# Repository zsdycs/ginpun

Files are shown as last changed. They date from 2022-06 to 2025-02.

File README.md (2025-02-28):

## GinPun

> 即：键盘（粤语）

偶然看到开源键盘库 [system76/launch](https://github.com/system76/launch) ，受其启发，故折腾起键盘。

目前有三款（[KB84](kb84/)、[SG_V1](sg_v1/)、[SG_V2](sg_v2/)）键盘，都是基于 ATmega 32U4 的。

更便宜一些的 ATmega 32A 的引导程序和最小系统也有提供，但是经过开发板打样测试，32A 的性能对于运行 QMK 来说还是捉襟见肘的，可玩性稍低一些。

例如：

- 在显示“从右向左”的五彩灯效时，会有停顿。
- 由于不支持 USB，通过 V-USB 实现的 USB，也不可以实现全键无冲。

## 指南💡

请移步阅读博客 [【一起做个机械键盘吧⌨️】](https://lipk.org/blog/2023-02-10-Let-s-make-a-keyboard)

## KB84

[KB84 于立创开源社区的链接](https://oshwhub.com/lipk/keyboard_1)

按键布局基于 system76 的 [launch](https://system76.com/accessories/launch) 键盘。由于特殊设计的按键配列，键帽非常难买到，键帽高度只能买到 XDA 的，可玩性不高。

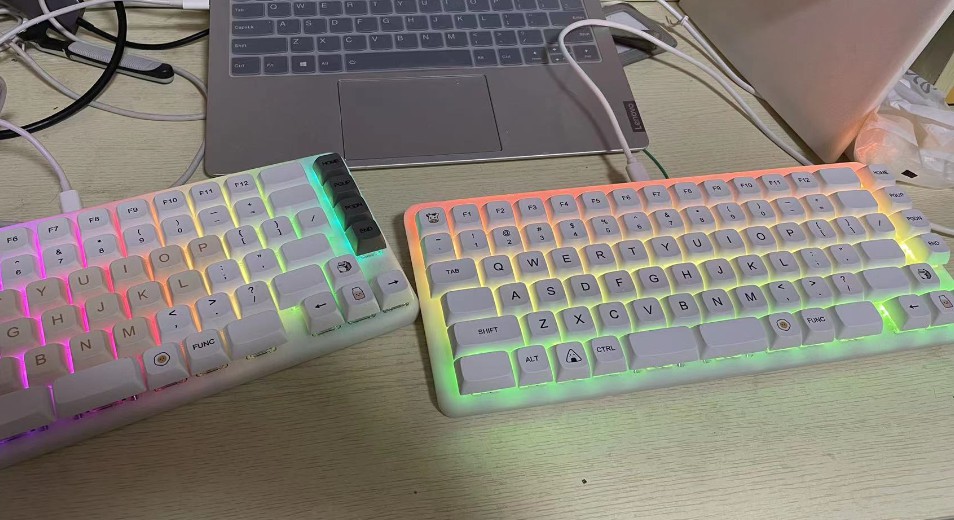
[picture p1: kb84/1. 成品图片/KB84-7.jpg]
KB84 成品图片1


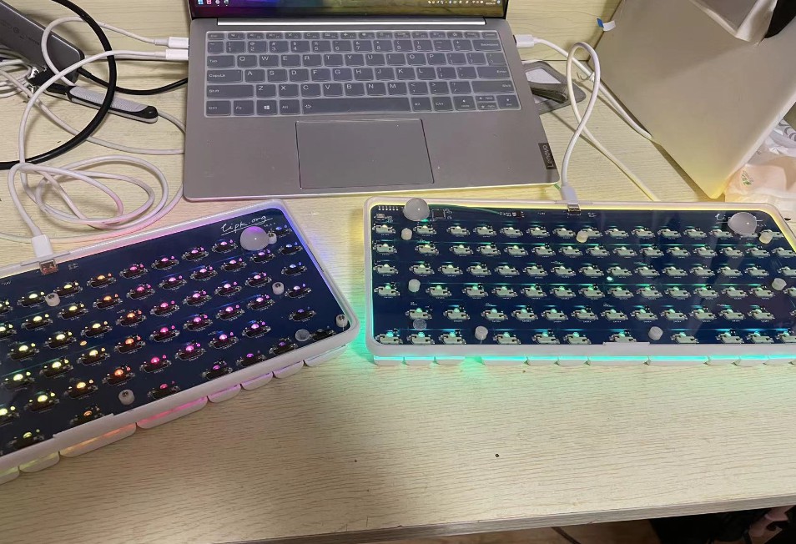
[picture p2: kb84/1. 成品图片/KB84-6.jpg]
KB84 成品图片2


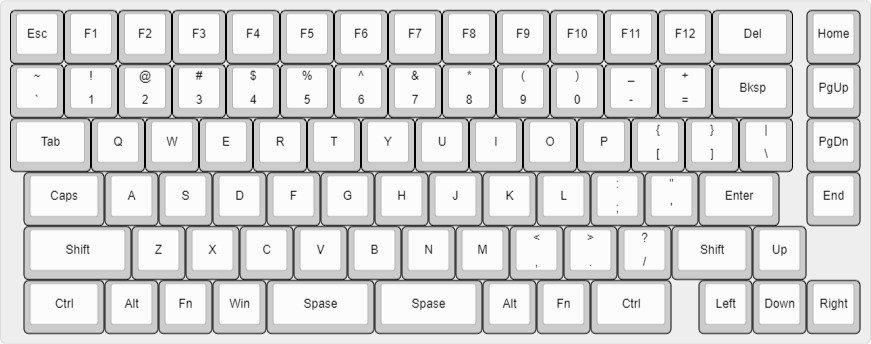
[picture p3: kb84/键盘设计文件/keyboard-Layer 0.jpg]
KB84 配列展示


### SG_V1

类标准 84 配列。

主要特点是第 6 行，“空格”键居中，有一个 1.5U 的 “CTRL” 靠近 “Z”、“X”、“C”、“V”，方便使用快捷键，所以键帽购买时也是稍微需要注意的。

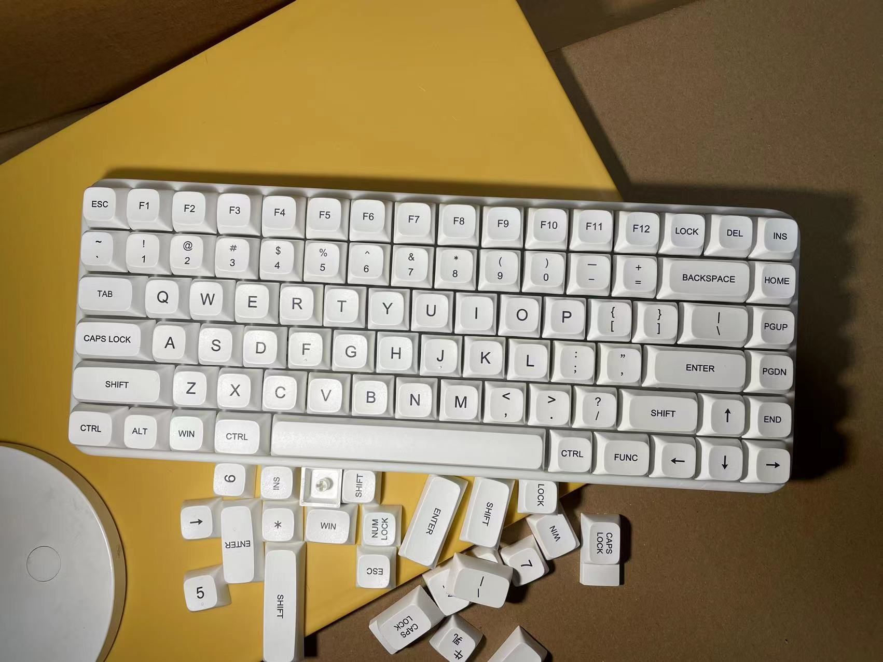
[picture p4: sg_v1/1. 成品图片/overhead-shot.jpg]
SG_V1 成品图片1


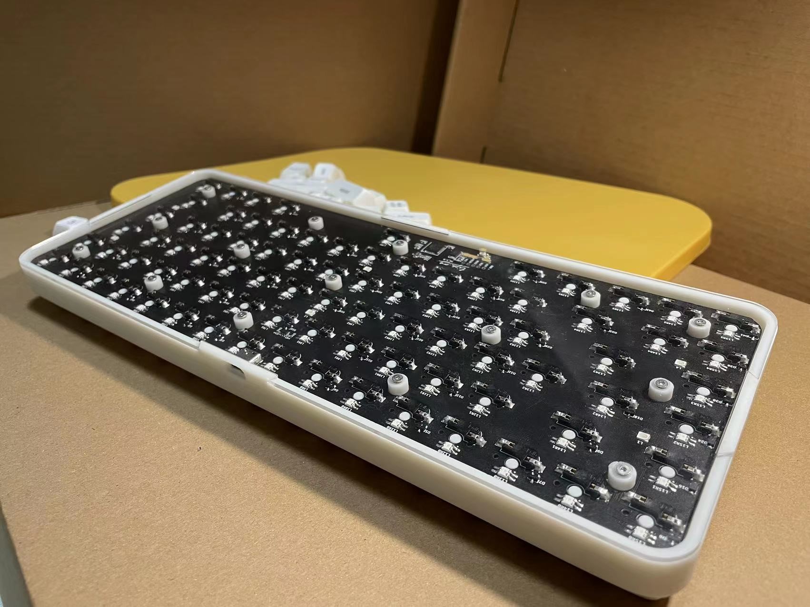
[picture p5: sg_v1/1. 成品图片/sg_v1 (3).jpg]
SG_V1 成品图片2


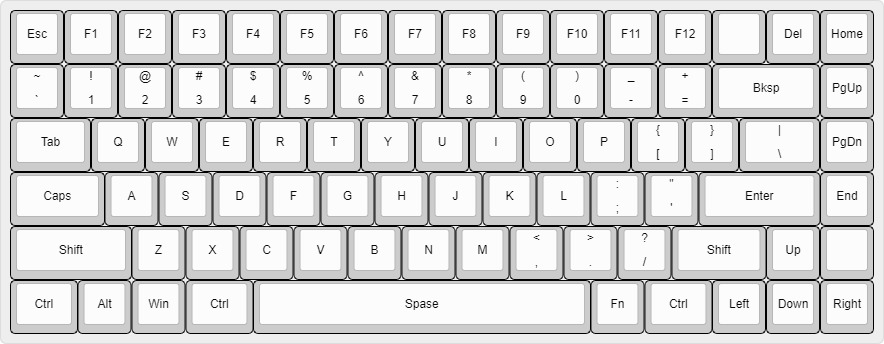
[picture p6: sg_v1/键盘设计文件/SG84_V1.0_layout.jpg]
SG_V1 配列展示


### SG_V2

[SG_V2 于立创开源硬件平台的链接](https://oshwhub.com/lipk/SG-61)

标准 87 配列，去掉右侧方向键和功能键，再去掉 F 区就是 SG_V2 的配列了。

由于是在“标准 87 配列”的基础上做删减，所以直接买 87 配列的键帽就好了，可玩性很高。

另外，此键盘使用 gasket 结构设计，而且使用磁吸安装，不需要一颗螺丝。

注：F 区，和方向键、功能键都在第 2 层，只要按一下功能键就可以切换到第 2 层了，不会有按键不够用的苦恼。

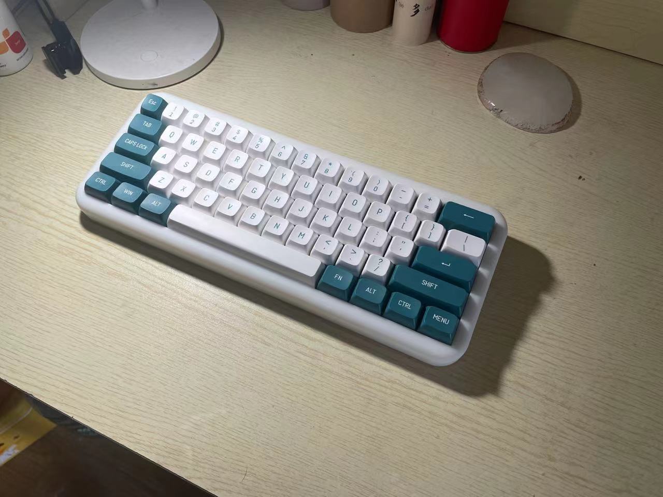
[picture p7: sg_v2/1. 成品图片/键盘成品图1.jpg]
SG_V2 成品图片1


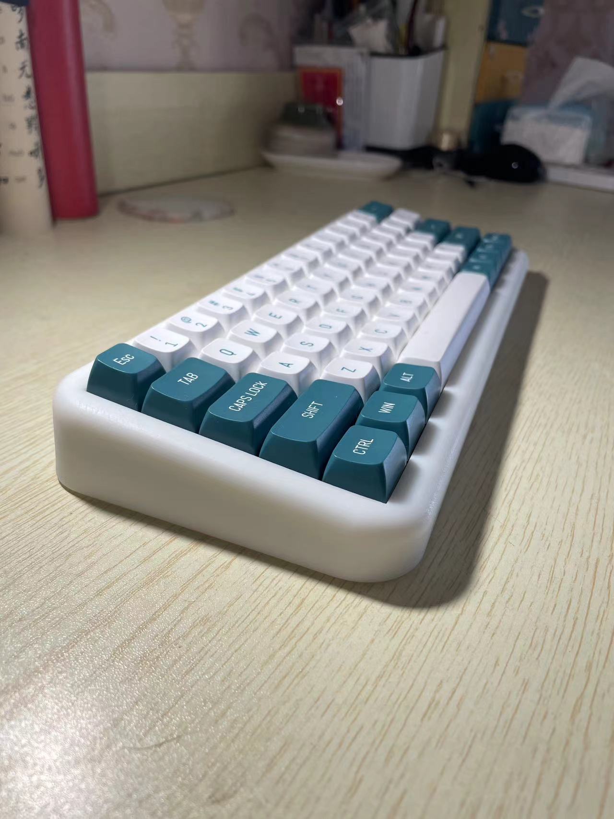
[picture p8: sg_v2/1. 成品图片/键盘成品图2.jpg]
SG_V2 成品图片2


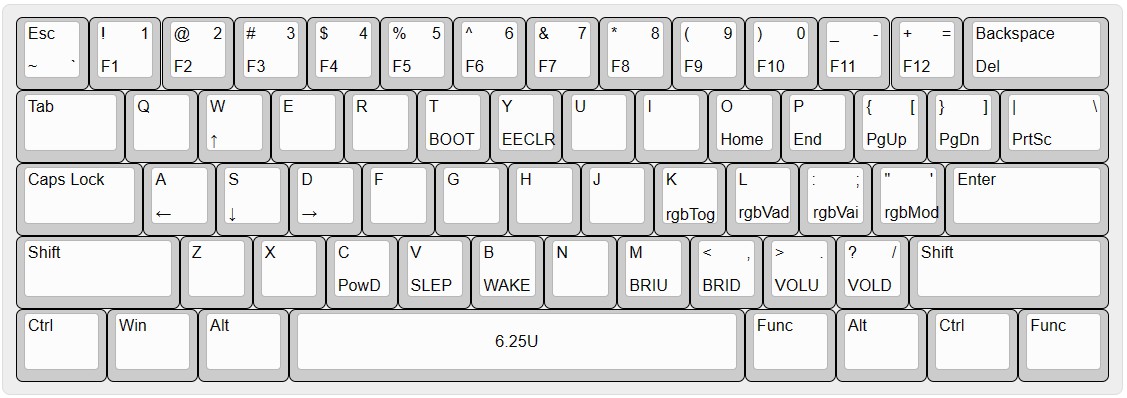
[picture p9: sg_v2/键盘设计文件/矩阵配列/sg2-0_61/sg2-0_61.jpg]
SG_V2 配列展示


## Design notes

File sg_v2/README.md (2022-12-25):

### SG v2



键盘成品图 1.jpg

键盘成品图 2.jpg

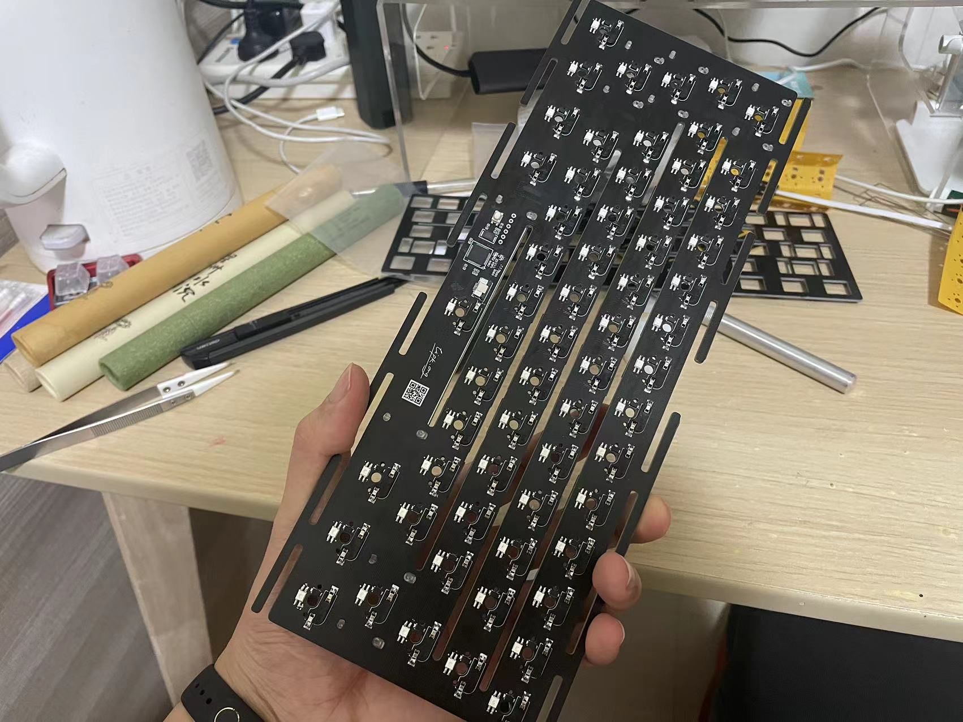
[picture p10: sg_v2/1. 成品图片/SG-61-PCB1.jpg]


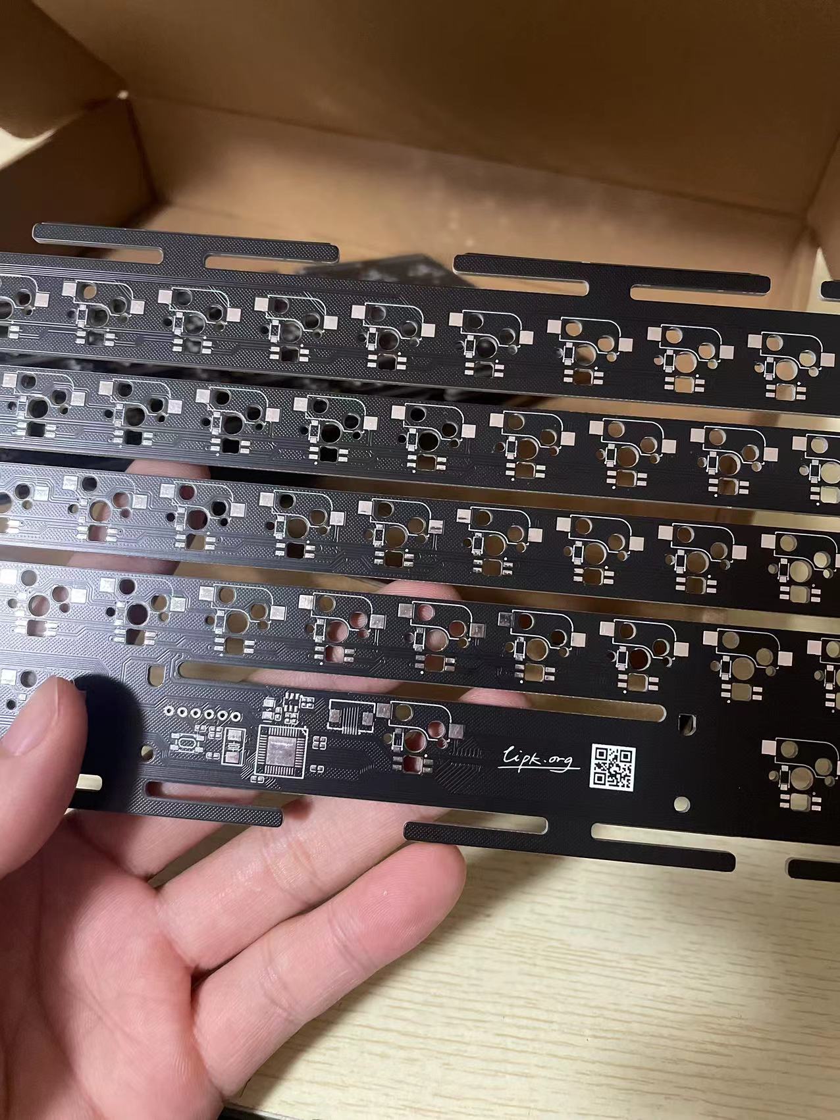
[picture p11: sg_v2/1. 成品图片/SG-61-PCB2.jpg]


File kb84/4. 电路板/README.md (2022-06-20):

### 版本说明

#### PCB v1.2 与 v1.3 的区别

1. v1.3 晶振改为了更薄的贴片式晶振

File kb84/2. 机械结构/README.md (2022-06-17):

### 开发环境

使用 [fusion 360](https://www.autodesk.com.cn/products/fusion-360/overview)，个人使用是免费的。

### 版本说明

#### 外壳 v1、v2 的区别

1. 外壳上下结构的螺丝柱调整，v2 更便于固定 PCB 的隔离柱的安装。
2. 底板 v1 为 1mm 厚，v2 改为了 2mm。
3. 固定螺丝 v1 M3*13，v2 M1.2*12。

#### 外壳 v2、v3 的区别

1. 外壳上下结构的螺丝柱调整，v3 增加了厚度，降低装配螺丝时塑料开裂的可能性。

#### PCB v1、v2 的区别

1. 晶振 二改为了更薄的贴片式晶振

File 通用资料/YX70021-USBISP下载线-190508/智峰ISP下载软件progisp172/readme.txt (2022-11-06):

PROGISP(Ver1.71)

最新特性
支持所有的AVR芯片的编程，支持AT89S51,AT89S52,sst89c5x,w78e5x,93cxx,24cxx,25xxx等
支持自定义并口下载编程器，
支持自定义串口的下载编程器 
支持USBASP编程器(支持最新版)
支持USBProg编程器(本工作室开发)
支持zf-007系列下载器（包括脱机下载器，免驱动版）
支持zf-008编程器（即可isp下载也可高压编程）
支持跳空写入（对于写入数据中有大量的未使用地址的flash，可以极大的提高写入速度）
支持预写熔丝（对于avr芯片可以预编程为高速熔丝位，极大的提高写入速度）
支持电源管理（需要对应的硬件支持）
支持3.3v/5v切换（需要对应的硬件支持）
支持写入系列号（可选大端，小端）
支持所有的时钟校正字写入flash或eeprom（avr芯片）
支持自定义编程芯片（xml文件管理）
支持自定义编程熔丝信息提示信息
支持自定义热键快捷键
支持自定义汉化信息提示
支持Unicode多国语言，在非中文环境下显示英文界面
支持工程管理--可以将所有的配置数据与编程数据打包为单一文件。
绿色软件，无需安装，占用资源少

特别提示：对于使用非智峰软件的编程器、下载器，不提供任何技术支持。

软件的使用遵循下面的许可协议（详细见LICENSE.txt）

详情请浏览   www.zhifengsoft.com

智峰软件工作室(mcu598@163.com)

附

智峰软件工作室简介(www.zhifengsoft.com)

宗旨：致力于嵌入式系统的软硬件开发，为工业控制及消费性产品提供技术支持，设计开发。

工作内容：主要从事单片机及pc的软硬件开发。嵌入式系统的软件开发与硬件设计,WINDOWS驱动程序开
发。包括电机控制,dvd,vcd,mp3,单片机的开发工具等。承接各类的控制系统的工程项目。

工作成果：

商用软件（包含硬件）
1、 数码管贴标机控制系统（89s8252）
2、 液晶屏贴标机控制系统（89c55WD）
3、 印刷分切机控制系统
4、 8头灌装机控制系统（AVR8515）
5、 智能洗手器(耗电6V,2uA)（pic12c508）
6、 自动冲便池软硬件(耗电6V,2uA)
7、 医药片剂包装控制系统
8、 智能绕线机控制系统
9、 智能磨刀机系统（AT89c51）
10、电子元件点数机（mega16）
11、VCD、功放的控制软件编写、DVD、mp3的开发
12、列车安全预警系统
13、桑拿浴管理系统
14、酒店管理系统
15、家庭智能电子类数十款产品（如热水器,电饭煲,电磁炉,微波炉,饮水机等）
16、工业设备的改造
17、弯管机
18、触控屏
19、类plc控制器

共享与免费软件
1、 并口监视软件
2、 股票分析软件
3、 avrgccide
4、 progisp

PROGISP编程软件许可协议 (LICENSE)

请仔细阅读以下使用许可，如果您不同意以下任何一点，请立即停止使用此软件。

智峰软件工作室，将本软件程序的最终使用许可权授予您。但您必须向本工作室作以下保证：

　　本《用户许可协议》（以下称《协议》）是您（个人或单一机构团体）与上述 PROGISP 软件（以下称“软件”或“软件产品”）版权所有人智峰软件工作室之间的法律协议。在您使用本软件产品之前,请务必阅读此《协议》，任何与《协议》有关的软件、电子文档等都应是按本协议的条款而授予您的，同时本《协议》亦适用于任何有关本软件产品的后期发行和升级。您一旦安装、复制、下裁、访问或以其它方式使用本软件产品，即表示您同意接受本《协议》各项条款的约束。如您不同意本《协议》的条款，那么，版权所有人智峰软件工作室则不予将本软件产品的使用权授予您。在这种情况下，您不得使用、复制或传播本软件产品。

　　软件产品许可协议
本软件产品受著作权法及国际著作权条约和其它知识产权法及条约的保护。本软件产品只许可使用，而不出售。软件以共享方式发布。

一、许可证的授予。本《协议》授予您下列权利：

1.1 安装和使用：
您可安装无限制数量的本软件产品来使用。

复制、分发和传播：
您可以复制、分发和传播无限制数量的软件产品，但您必须保证每一份复制、分发和传播都必须是完整和真实的，包括所有有关本软件产品的软件、电子文档，版权和商标宣言，亦包括本协议。
本软件可以独立分发亦可随同其他软件一起分发，但如因此而引起任何问题，版权人将不予承担任何责任。

1.2 其它权利和限制说明。

禁止反向工程、反向编译和反向汇编：
您不得对本软件产品进行反向工程、反向编译和反向汇编。除非适用法律明文允许上述活动，否则您必须遵守此协议限制。

组件的分隔：
本软件产品是被当成一个单一产品而被授予许可使用，不得将各个部分分开用于任何目的行动。

软件产品转让：
在不保留任何副本，您可以将本“软件产品”（包括所有组成部分零件、媒介和印刷材料、任何更新版本、本《协议》等）全部转让，并且受让人接受本《协议》的各项条件下，您可永久转让您在本《协议》下的所有权利。如果本“软件产品”为更新本，转让时必须包括本“软件产品”所有前版本。

终止：
如您未遵守本《协议》的各项条件，在不损害其它权利的情况下，版权人可将本《协议》终止。如发生此种情况，则您必须销毁“软件产品”及其各部分的所有副本。

二、服务方式

2.1 软件的取得

用户可以从包括（但不仅限于）因特网、BBS、光盘、商业发行渠道等各种方式获取共享软件，包括免费下载、购买光盘、软盘等载体而获得。用户获得软件的方式应该是免费的，即使是通过购买光盘、软盘等载体的方式获得，也不能视为已经获得该软件的使用权。 
　
2.2 软件的注册

软件在未注册之前，相应的软件功能可以是完全的，可以是限制性的。软件功能限制的方式包括（但不仅限于）功能不完全、有使用次数或时间限制等。用户在先试用共享软件认为满意后，付费后即成为注册用户。根据相应软件开发者的承诺，注册用户可以享受到相应的待遇，包括：升级、技术服务、疑问解答等。用户付费成功后，软件开发者通过电子邮件向用户发送注册码或用其他方式完成对用户的服务。

2.3 共享软件的服务

软件的技术支持和升级服务由软件开发者负责。注册用户在使用相应软件过程中，如遇有问题，应该认真阅读相应软件包中的文档。如果注册用户所提问题已经列举在文档中，软件开发者可以拒绝回复。用户在支付注册费时，购买的仅仅是相应软件的当前版本的使用授权。

三、免费下载
本软件产品免费提供给您使用。您可在互联网(http://www.zhifengsoft.com)上免费下载。本软件产品版权人智峰软件工作室拥有最终解释权。

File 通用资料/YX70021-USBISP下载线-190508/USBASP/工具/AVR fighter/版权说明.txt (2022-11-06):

共享软件 AVR_fighter for USBASP

支持编程器具类型：
目前只支持:USBASP  (接口类型:USB)

/********************************************************************/
软件名称: AVR_fighter 
用    途: AVR单片机ISP下载编程软件 
版    本: 1.0 (LICENSE)
操作系统: Win98,Win2000,WinMe,WinXP,win2003 (注:Windows Vista未测试)
建议设置: 屏幕分辩率 1024 X 768 以上

请仔细阅读以下使用许可，如果您不同意以下任何一点，请立即停止使用此软件。

    ZS软件工作室将本软件程序的最终使用许可权授予您。但您必须向本工作室及作者:zhb2000本人作以下保证：

　　本<<用户许可协议>>是您(个人或单一机构团体)与AVR_fighter软件(以下称“软件”或“软件产品”)版权所有人zhb2000及其ZS工作室之间的法律协议。在您使用本软件产品之前,请务必阅读此<<协议>>，任何与<<协议>>有关的软件、电子文档等都应是按本协议的条款而授予您的，同时本<<协议>>亦适用于任何有关本软件产品的后期发行和升级。您一旦安装、复制、下裁、访问或以其它方式使用本软件产品，即表示您同意接受本<<协议>>各项条款的约束。如您不同意本<<协议>>的条款，那么，版权所有人zhb2000及其ZS工作室则不予将本软件产品的使用权授予您。在这种情况下，您不得使用、复制或传播本软件产品。

/********************************************************************/
软件产品许可协议:
    本软件产品受著作权法及国际著作权条约和其它知识产权法及条约的保护。本软件产品只许可使用，而不出售。软件以共享方式发布。如果要将本软件用于商业用途请与版权所有人zhb2000及ZS工作室(注:zhb2000代表ZS工作室行使权利)联系并取得受权，否则其将承担一切法律责任。

1、您可安装无限制数量的本软件产品来使用。您可以复制、分发和传播无限制数量的软件产品，但您必须保证每一份复制、分发和传播都必须是完整和真实的，包括所有有关本软件产品的软件、电子文档，版权和商标宣言，亦包括本协议。本软件可以独立分发亦可随同其他软件一起分发，但如因此而引起任何问题，版权人将不予承担任何责任。

2、您不得对本软件产品进行任何形式的反向工程、反向编译和反向汇编。除非适用法律明文允许上述活动，否则您必须遵守此协议限制。

3、如果您未遵守本<<用户许可协议>>的各项条件，在不损害其它权利的情况下，版权人可将本<<用户许可协议>>终止。如发生此种情况，则您必须销毁“软件产品”及其各部分的所有副本。

/********************************************************************/
软件的获得:
    用户可以从包括(但不仅限于)因特网、BBS、光盘、商业发行渠道等各种方式获取本共享软件，包括免费下载、购买光盘、软盘等载体而获得。用户获得软件的方式应该是免费的，即使是通过购买光盘、软盘等载体的方式获得，也不能视为已经获得该软件的所有权。
    本软件产品免费提供给您使用。软件产品版权人zhb2000及其ZS软件工作室对此拥有最终解释权。

/********************************************************************/
鸣谢: 
1、网站:
    www.ouravr.com              我们的AVR
    www.01mcu.net               数码微控
    www.mculib.com              三毛电子
    www.chipart.cn              芯艺设计室
    www.fjmcu.com               精诚电子设计
    www.99eda.com               EDA资讯网
    www.zhifengsoft.com         智峰软件
    www.avrfreaks.net
    www.basicavr.com
    www.iccavr.com
    
2、个人: 
    (www.ouravr.com网站上的朋友们，排名不分先后)
    machao (马老师)
    andy 红日
    donkey 知秋
    HJJourAVR
    testcode
    ilan2003 小松工程
    gxlujd 彩虹
    JAMESKING
    jimo
    ecat
    ilikemcu 我爱单片机
    alisha
    cltemail 常乐天
    zjykx 绿叶
    qwernet 小俊
    avrboy =單騙皇帝=
    zhifeng
    dfgeoff 嗜血蜗牛
    ainet
    314forever
    wxfhw
    bluerain 网络棋侠
    ......
    还有其它对我关心帮助的朋友们！

特别感谢:
    armok 阿莫 (ouravr网站站长)给我们提供了这么一个好的学习交流的空间。

    314forever、wxfhw 、bluerain 网络棋侠(在他们的积极测试与热情帮助下，使AVR_fighter一步步完善，没有他们的帮助就不可能有AVR_fighter现在的成功！)

日期:20080221

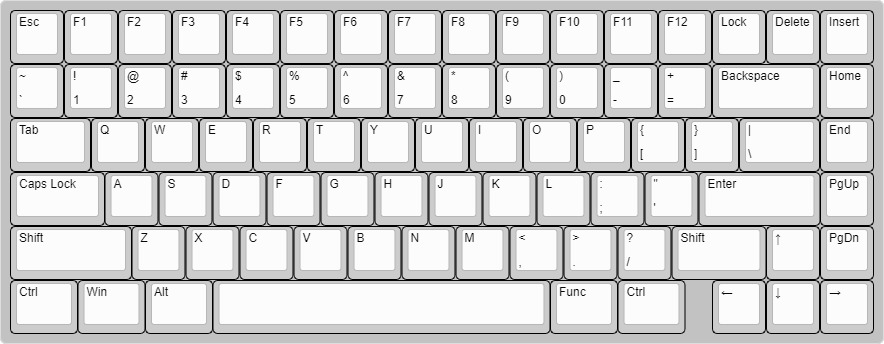
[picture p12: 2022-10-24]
sg_v2/键盘设计文件/矩阵配列/sg2-0_83/sg2-0_83.jpg

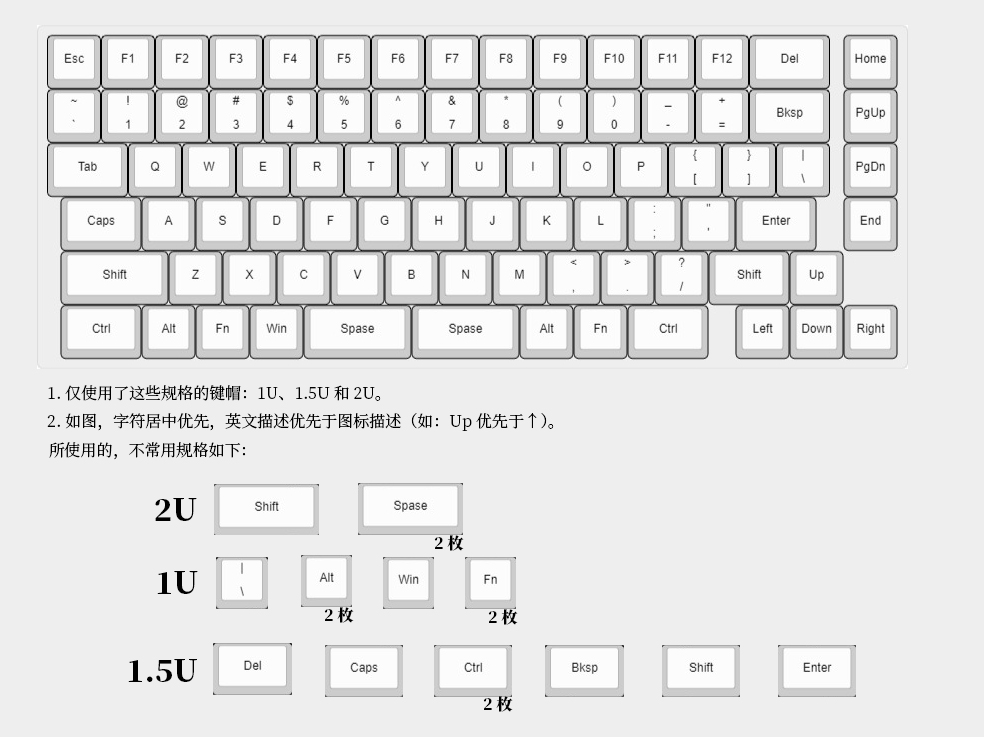
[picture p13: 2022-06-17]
kb84/键盘设计文件/键帽规格说明.jpg

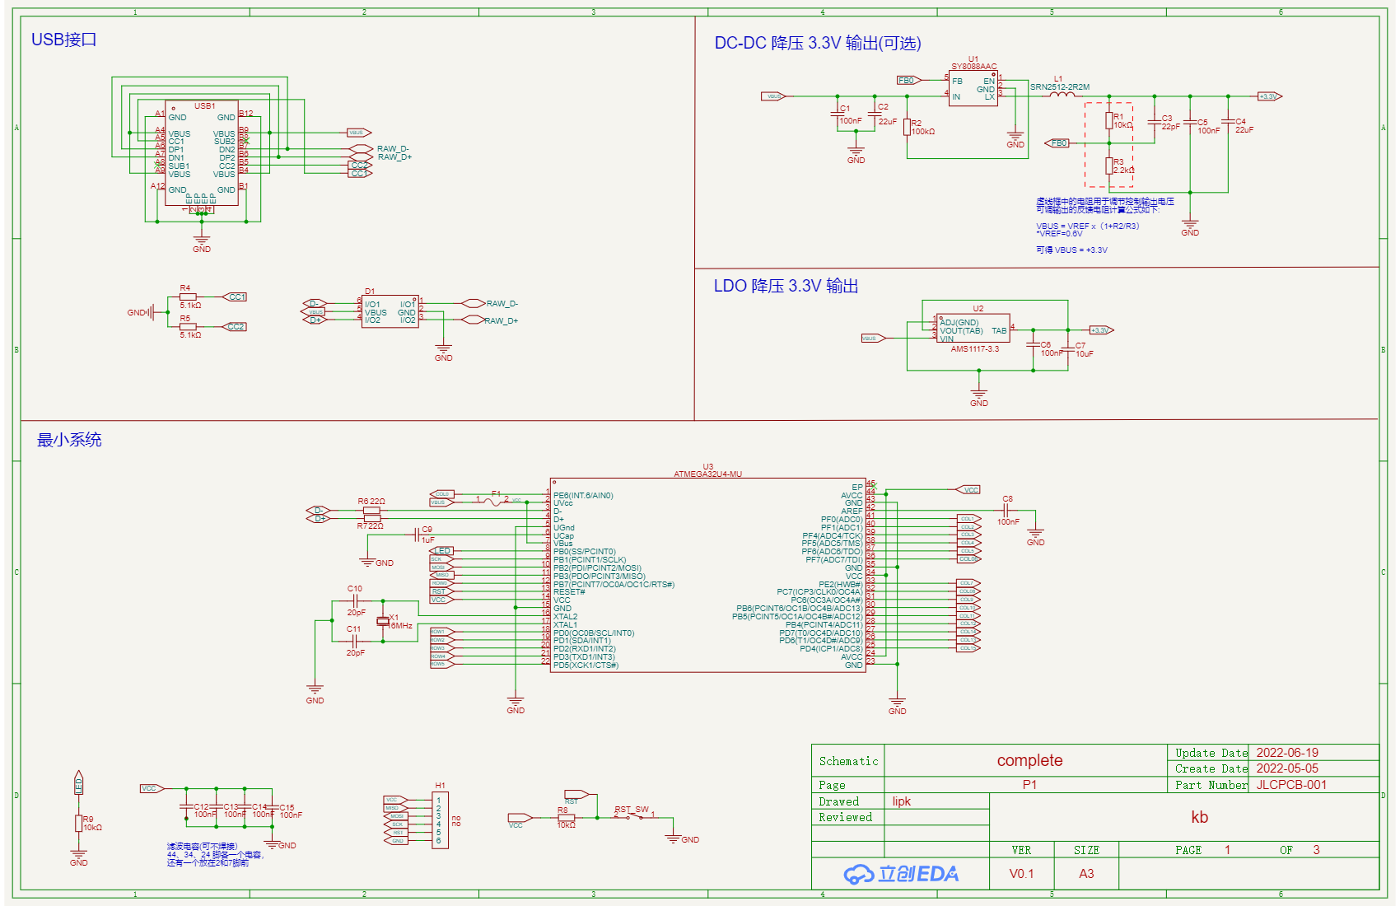
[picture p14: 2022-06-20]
kb84/3. 原理图/SCH_kb_32u4_v1.3_P1.png

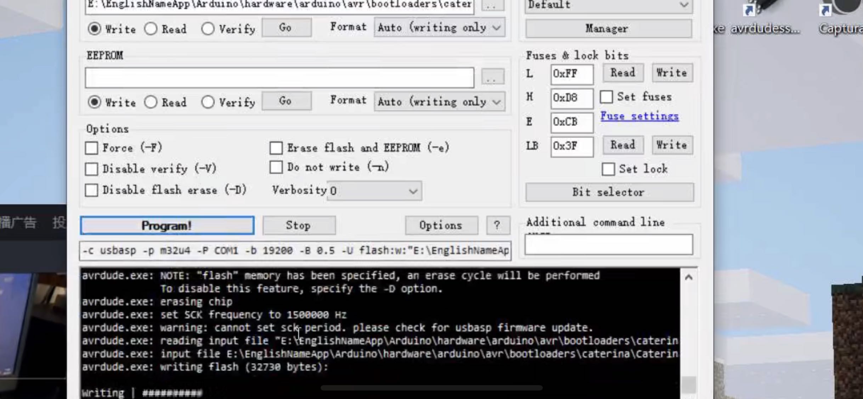
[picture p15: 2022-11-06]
通用资料/m32u熔丝位.jpg

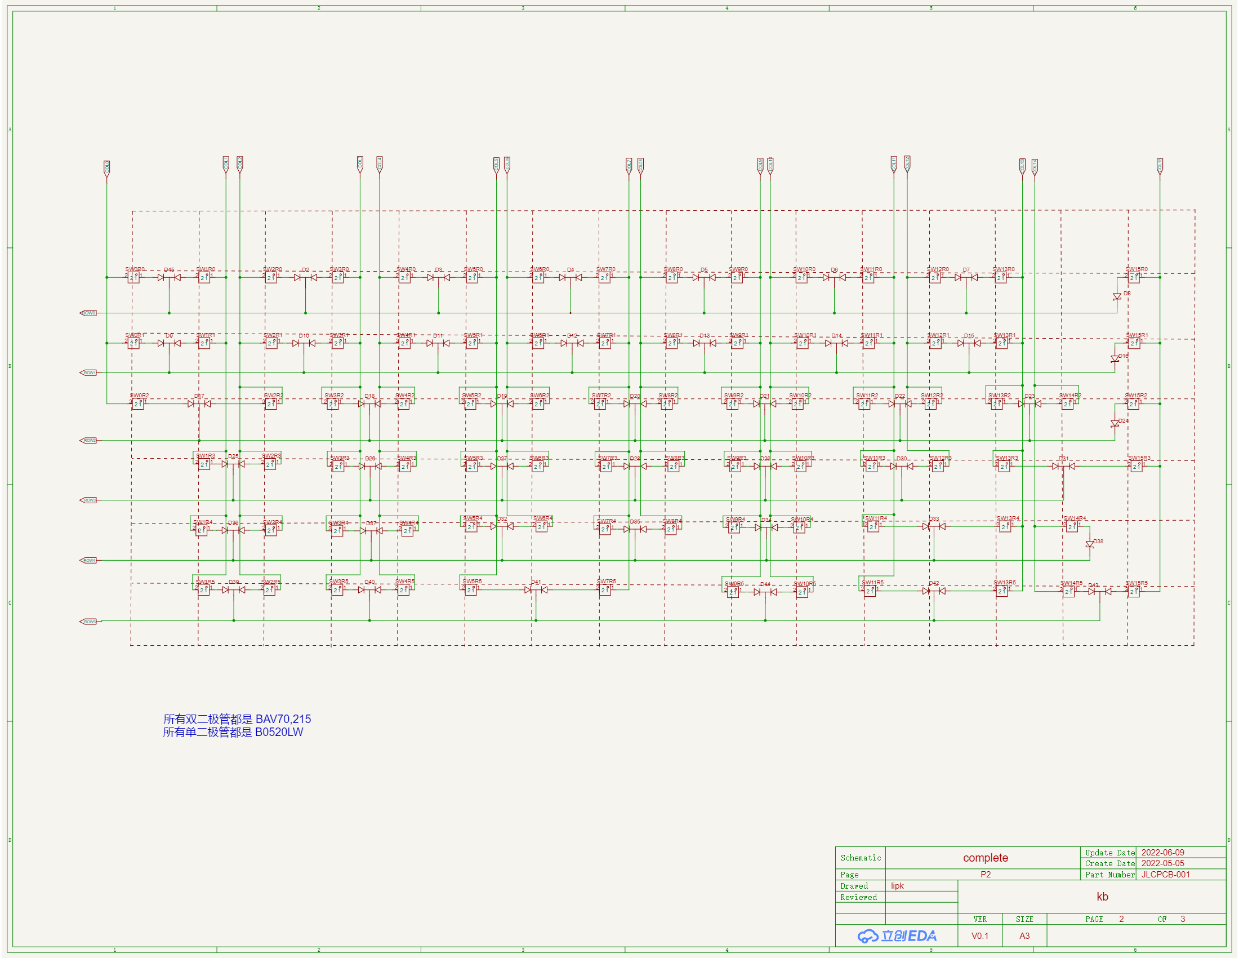
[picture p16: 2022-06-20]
kb84/3. 原理图/SCH_kb_32u4_v1.3_P3.png

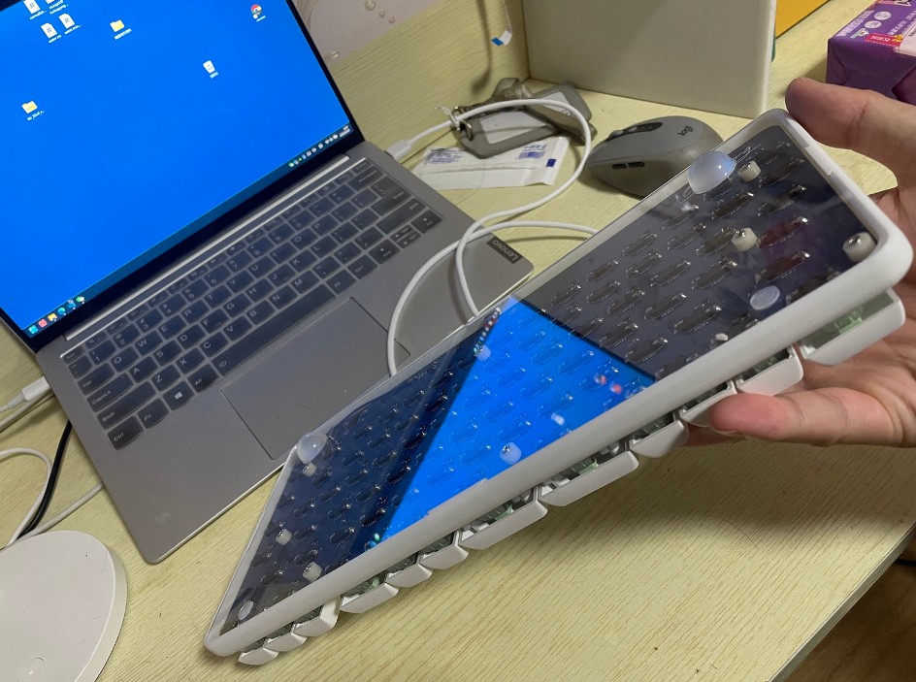
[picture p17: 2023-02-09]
kb84/1. 成品图片/KB84-3.jpg

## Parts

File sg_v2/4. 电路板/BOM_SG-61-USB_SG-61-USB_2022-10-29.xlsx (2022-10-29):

No. | Quantity | Comment | Designator | Footprint | Value | Manufacturer Part | Manufacturer | Supplier Part | Supplier
1 | 1 | 0.5K-DX-6PWBG | FPC1 | FPC-SMD_6P-P0.50_DEALON_0.5K-DX-6PWB |  | 0.5K-DX-6PWBG | HDGC(华德共创) | C2911878 | LCSC
2 | 1 | KH-TYPE-C-16P | USB1 | usb-c-smd_kh-type-c-16p |  | KH-TYPE-C-16P | kinghelm(金航标) | C709357 | LCSC

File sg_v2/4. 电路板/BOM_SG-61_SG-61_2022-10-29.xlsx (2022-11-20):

No. | Quantity | Comment | Designator | Footprint | Value | Manufacturer Part | Manufacturer | Supplier Part | Supplier
1 | 5 | 100nF | C1,C5,C6,C7,C8 | 0402 | 100nF |  |  | C1525
2 | 1 | 1uF | C2 | 0402 | 1uF |  |  | C1525
3 | 2 | 20pF | C3,C4 | 0402 | 20pF |  |  | C1525
4 | 61 | DSR1M | D1,D2,D3,D4,D5,D6,D7,D8,D9,D10,D11,D12,D13,D14,D15,D16,D17,D18,D19,D20,D21,D22,D23,D24,D25,D26,D27,D28,D29,D30,D31,D32,D33,D34,D35,D36,D37,D38,D39,D40,D41,D42,D43,D44,D45,D46,D47,D48,D49,D50,D51,D52,D53,D54,D55,D56,D57,D58,D59,D60,D61 | sod-123_l2.8-w1.8-ls3.7-rd |  | DSR1M | FUXINSEMI(富芯森美) | C908221 | LCSC
5 | 1 | USBLC6-2SC6 | D62 | sot-23-6_l2.9-w1.6-p0.95-ls2.8-bl |  | USBLC6-2SC6 | UMW(友台半导体) | C2687116 | LCSC
6 | 1 | BSMD0805-110-6V | F1 | f0805 |  | BSMD0805-110-6V | BHFUSE(佰宏) | C883113 | LCSC
7 | 1 | 0.5K-DX-6PWBG | FPC1 | FPC-SMD_6P-P0.50_DEALON_0.5K-DX-6PWB |  | 0.5K-DX-6PWBG | HDGC(华德共创) | C2911878 | LCSC
8 | 61 | XL-3528RGBW-WS2812B | L0R0,L0R1,L0R2,L0R4,L1R0,L1R3,L1R4,L2R0,L2R1,L2R2,L2R3,L3R0,L3R1,L3R2,L3R3,L3R4,L4R0,L4R1,L4R2,L4R3,L5R0,L5R1,L5R2,L5R3,L6R0,L6R1,L6R2,L6R3,L6R4,L7R0,L7R1,L7R2,L7R3,L8R0,L8R1,L8R2,L8R3,L9R0,L9R1,L9R2,L9R3,L10R0,L10R1,L10R2,L10R3,L10R4,L11R0,L11R1,L11R2,L11R3,L11R4,L12R0,L12R1,L12R2,L13R1,L13R2,L13R3,L13R4,L14R0,L14R1,L14R4 | ws2812-3528 |  | XL-3528RGBW-WS2812B | XINGLIGHT(成兴光) | C2890364 | LCSC
9 | 2 | 5.1kΩ | R1,R2 | 0402 | 5.1kΩ
10 | 2 | 22Ω | R3,R4 | 0402 | 22Ω
11 | 1 | 10K | R5 | 0402 | 10K
12 | 61 | CPG151101S11 | SW0R0,SW0R1,SW0R2,SW0R4,SW1R0,SW1R3,SW1R4,SW2R0,SW2R1,SW2R2,SW2R3,SW2R4,SW3R0,SW3R1,SW3R2,SW3R3,SW4R0,SW4R1,SW4R2,SW4R3,SW5R0,SW5R1,SW5R2,SW5R3,SW6R0,SW6R1,SW6R2,SW6R3,SW6R4,SW7R0,SW7R1,SW7R2,SW7R3,SW8R0,SW8R1,SW8R2,SW8R3,SW9R0,SW9R1,SW9R2,SW9R3,SW10R0,SW10R1,SW10R2,SW10R3,SW10R4,SW11R0,SW11R1,SW11R2,SW11R3,SW11R4,SW12R0,SW12R1,SW12R2,SW13R1,SW13R2,SW13R3,SW13R4,SW14R0,SW14R1,SW14R4 | kailh_socket_mx |  | CPG151101S11 |  | C9900013508 | LCSC
13 | 1 | TS-1145A-B-A | SW_RST | sw-smd_4p-l4.2-w3.2-p2.15-ls5.2 |  | TS-1145A-B-A | XKB Connectivity(中国星坤) | C318904 | LCSC
14 | 1 | ATMEGA32U4-MU | U1 | vqfn-44_l7.0-w7.0-p0.50-bl-ep5.2 |  | ATMEGA32U4-MU | MICROCHIP(美国微芯) | C112161 | LCSC
15 | 1 | 16MHz | X1 | osc-smd_l5.0-w3.2 | 16MHz | X503216MSB2GI | YXC扬兴科技 | C112572 | LCSC

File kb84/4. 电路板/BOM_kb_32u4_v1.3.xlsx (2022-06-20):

Quantity | Device | Designator | Footprint | Value
1 | CL10A106MQ8NNNC | C7 | C0603 | 10uF
5 | 0603B104K500NT | C8,C12,C13,C14,C15 | C0603 | 100nF
1 | CL21B105KBFNNNE | C9 | C0805 | 1uF
2 | 0603CG200J500NT | C10,C11 | C0603 | 20pF
8 | CL05A225MQ5NSNC | C17,C18,C19,C20,C21,C22,C23,C24 | C0402 | 2.2uF
1 | USBLC6-2SC6 | D1 | SOT-23-6_L2.9-W1.6-P0.95-LS2.8-BL
40 | BAV74,215 | D2,D3,D4,D5,D6,D7,D9,D10,D11,D12,D13,D14,D15,D17,D18,D19,D20,D21,D22,D23,D25,D26,D27,D28,D29,D30,D31,D32,D33,D34,D35,D36,D37,D39,D40,D41,D42,D43,D44,D45 | SOT-23_L2.9-W1.3-P1.90-LS2.4-BR
4 | B0520LW | D8,D16,D24,D38 | SOD-123_L2.7-W1.6-LS3.7-RD-1
1 | BSMD0805-110-6V | F1 | F0805
84 | SK6805-EC15 | L0R0,L0R1,L0R2,L1R0,L1R1,L1R3,L1R4,L1R5,L2R0,L2R1,L2R2,L2R3,L2R4,L2R5,L3R0,L3R1,L3R2,L3R3,L3R4,L3R5,L4R0,L4R1,L4R2,L4R3,L4R4,L4R5,L5R0,L5R1,L5R2,L5R3,L5R4,L5R5,L6R0,L6R1,L6R2,L6R3,L6R4,L7R0,L7R1,L7R2,L7R3,L7R4,L7R5,L8R0,L8R1,L8R2,L8R3,L8R4,L9R0,L9R1,L9R2,L9R3,L9R4,L9R5,L10R0,L10R1,L10R2,L10R3,L10R4,L10R5,L11R0,L11R1,L11R2,L11R3,L11R4,L11R5,L12R0,L12R1,L12R2,L12R3,L13R0,L13R1,L13R2,L13R3,L13R4,L13R5,L14R2,L14R4,L14R5,L15R0,L15R1,L15R2,L15R3,L15R5 | LED-SMD_4P-L1.5-W1.5-BL
2 | RS-05K5101FT | R4,R5 | R0805 | 5.1kΩ
2 | 0603WAF220JT5E | R6,R7 | R0603 | 22Ω
1 | 0603WAF1002T5E | R8 | R0603 | 10kΩ
1 | 0402WGF1002TCE | R9 | R0402 | 10kΩ
1 | 0402WGF4990TCE | R10 | R0402 | 499
1 | K2-1107ST-A4DW-06 | RST_SW | KEY-SMD_L6.2-W3.6-LS8.0
84 | CPG151101S11 | SW0R0,SW0R1,SW0R2,SW1R0,SW1R1,SW1R3,SW1R4,SW1R5,SW2R0,SW2R1,SW2R2,SW2R3,SW2R4,SW2R5,SW3R0,SW3R1,SW3R2,SW3R3,SW3R4,SW3R5,SW4R0,SW4R1,SW4R2,SW4R3,SW4R4,SW4R5,SW5R0,SW5R1,SW5R2,SW5R3,SW5R4,SW5R5,SW6R0,SW6R1,SW6R2,SW6R3,SW6R4,SW7R0,SW7R1,SW7R2,SW7R3,SW7R4,SW7R5,SW8R0,SW8R1,SW8R2,SW8R3,SW8R4,SW9R0,SW9R1,SW9R2,SW9R3,SW9R4,SW9R5,SW10R0,SW10R1,SW10R2,SW10R3,SW10R4,SW10R5,SW11R0,SW11R1,SW11R2,SW11R3,SW11R4,SW11R5,SW12R0,SW12R1,SW12R2,SW12R3,SW13R0,SW13R1,SW13R2,SW13R3,SW13R4,SW13R5,SW14R2,SW14R4,SW14R5,SW15R0,SW15R1,SW15R2,SW15R3,SW15R5 | Kailh_socket_MX
1 | AMS1117-3.3 | U2 | SOT-223-4_L6.5-W3.5-P2.30-LS7.0-BR
1 | ATMEGA32U4-MU | U3 | VQFN-44_L7.0-W7.0-P0.50-BL-EP5.2
1 | KH-TYPE-C-16P | USB1 | USB-C-SMD_KH-TYPE-C-16P
1 | X503216MSB2GI | X1 | OSC-SMD_L5.0-W3.2 | 16MHz

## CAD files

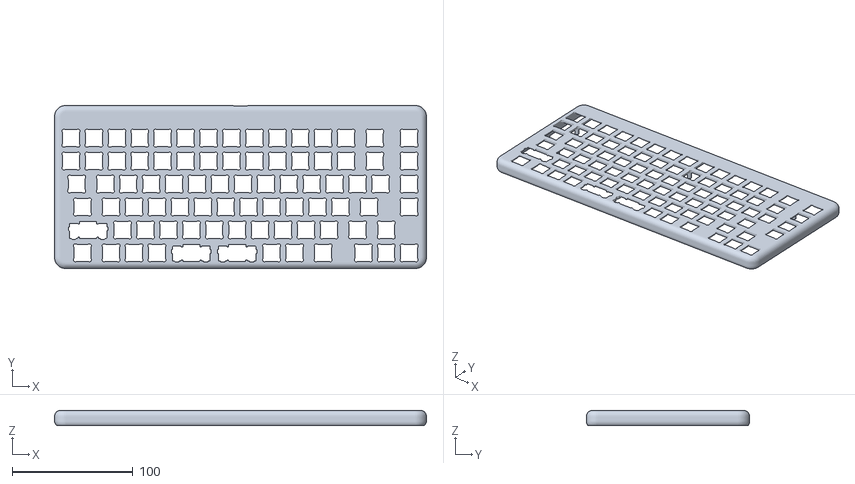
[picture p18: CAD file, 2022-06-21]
kb84/2. 机械结构/外壳 v3/shell v3.stl
308.3 x 135.1 x 12.6

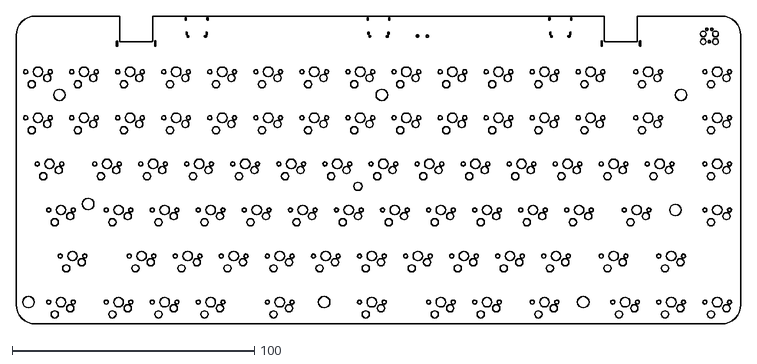
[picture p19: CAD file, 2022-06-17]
kb84/键盘设计文件/键盘PCB板框.dxf
299.0 x 127.0

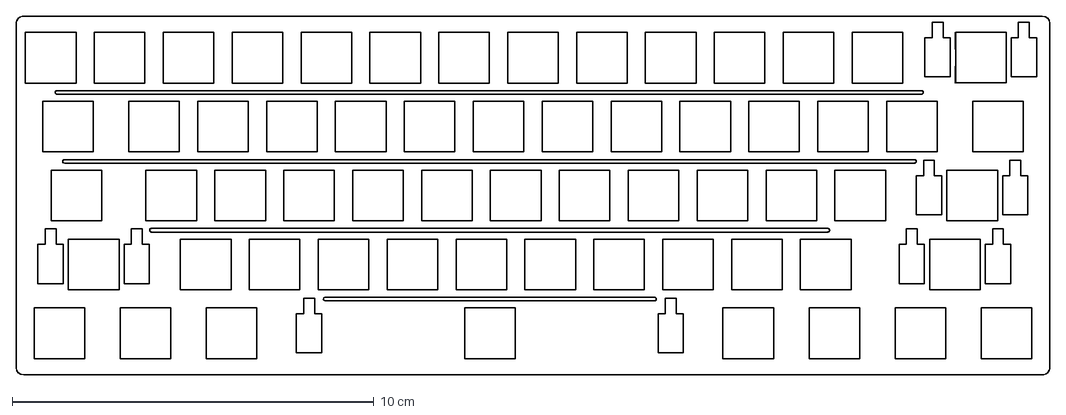
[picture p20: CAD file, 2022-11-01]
sg_v2/2. 机械结构/SG-61-定位板.dxf
28.6 x 9.92 cm

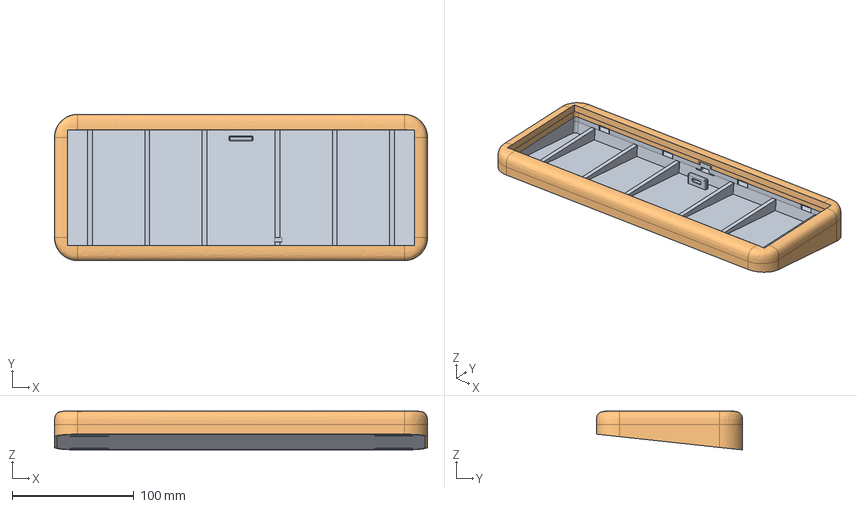
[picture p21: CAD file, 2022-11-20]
sg_v2/2. 机械结构/外壳/SG-61 v46.step
306.9 x 120.4 x 32.0 mm

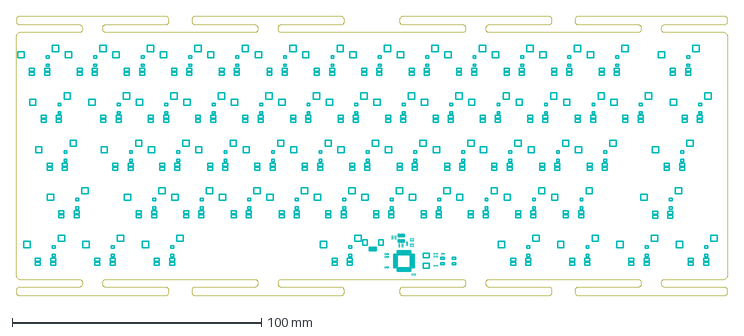
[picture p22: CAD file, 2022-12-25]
sg_v2/4. 电路板/DXF_SG-61_2022-12-25_底层锡膏.dxf
285.8 x 112.3 mm

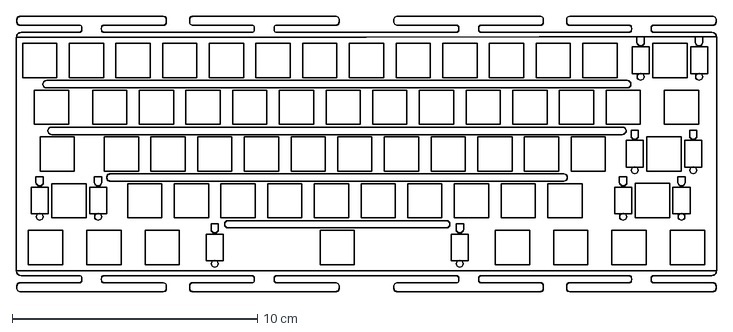
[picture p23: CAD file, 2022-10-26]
sg_v2/键盘设计文件/定位板/sg2-0_61/sg2-0_61.dxf
28.6 x 11.2 cm

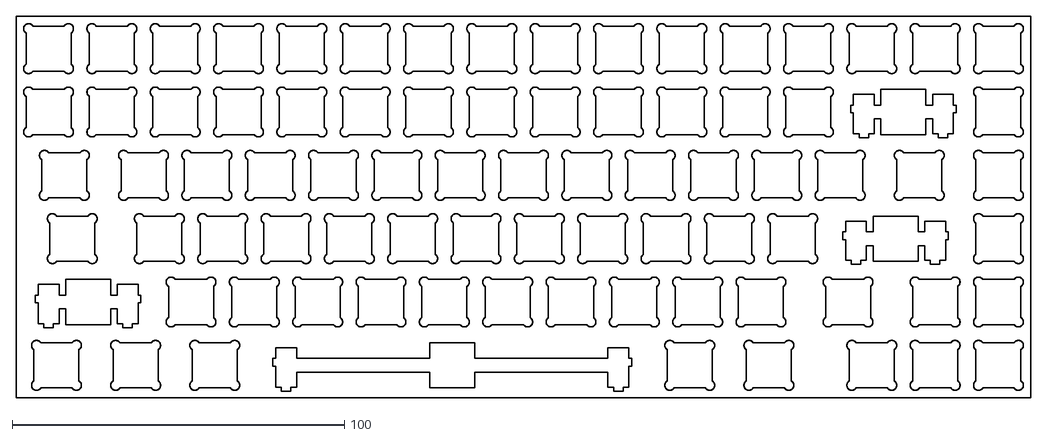
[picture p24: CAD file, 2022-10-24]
sg_v2/键盘设计文件/定位板/sg2-0_83/sg2-0_83.dxf
305.2 x 114.7

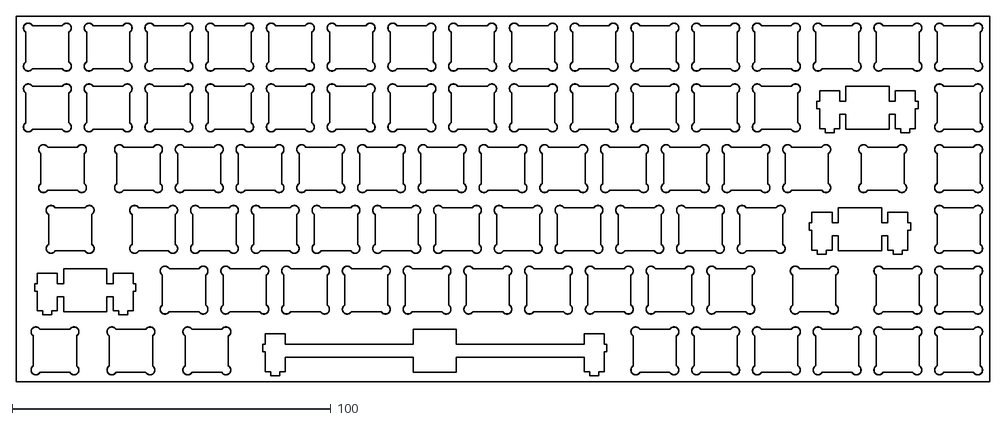
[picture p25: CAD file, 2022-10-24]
sg_v2/键盘设计文件/定位板/sg2-0_84/sg2-0_84.dxf
305.2 x 114.7

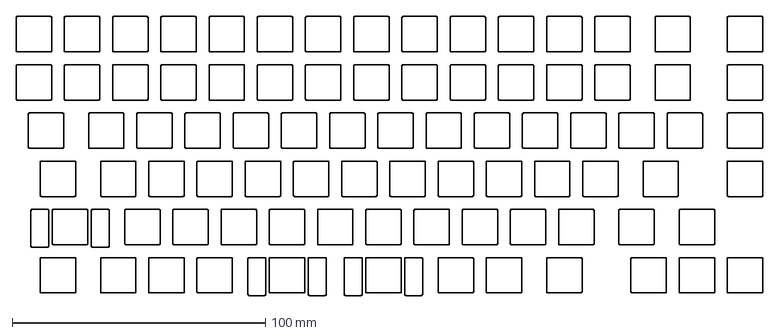
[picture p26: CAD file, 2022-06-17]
kb84/键盘设计文件/kbplate.dxf
295.0 x 110.2 mm

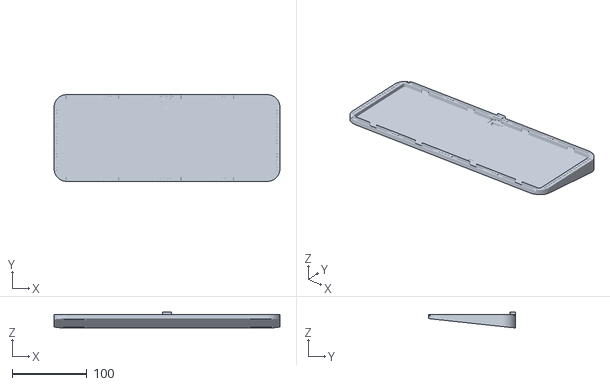
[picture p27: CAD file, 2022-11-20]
sg_v2/2. 机械结构/外壳/SG-61 v35 底盖.stl
302.7 x 116.2 x 21.4

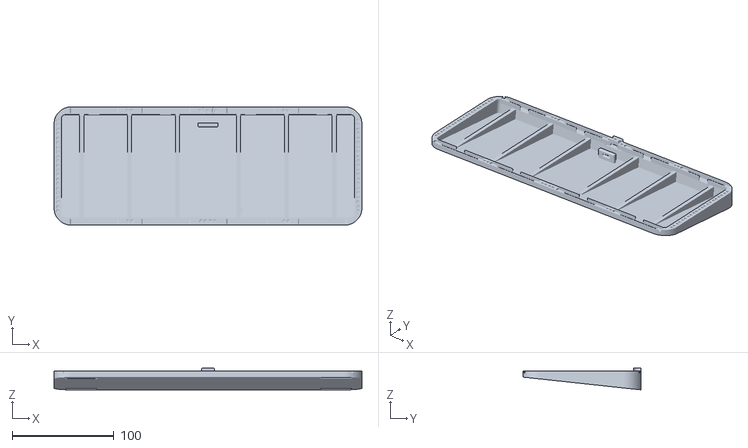
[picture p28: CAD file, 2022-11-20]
sg_v2/2. 机械结构/外壳/SG-61 v43底壳.stl
302.7 x 116.2 x 21.4

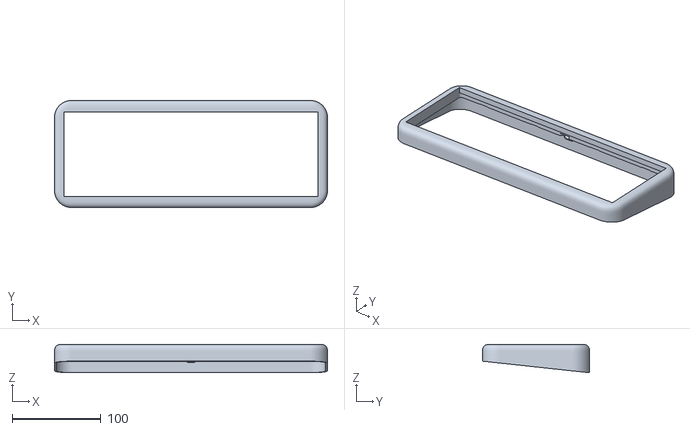
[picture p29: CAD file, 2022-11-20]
sg_v2/2. 机械结构/外壳/SG-61 v44上壳.stl
306.9 x 120.4 x 32.0

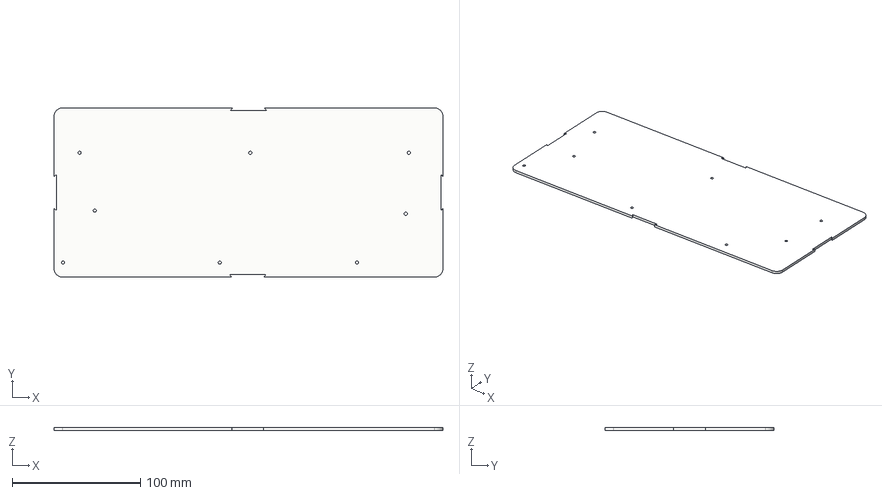
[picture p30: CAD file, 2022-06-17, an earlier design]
kb84/2. 机械结构/外壳 v2/bottom_plate v2.step
303.0 x 131.9 x 2.30 mm

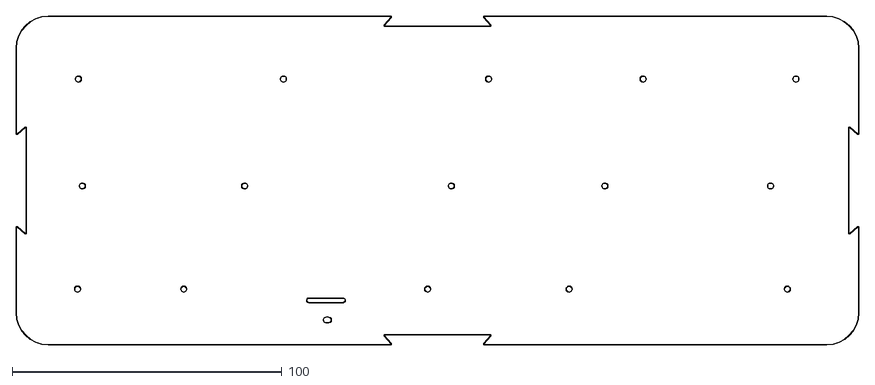
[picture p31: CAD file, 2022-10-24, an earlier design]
sg_v1/2. 机械结构/SG84_V1.0_shell_v13_plate.dxf
312.4 x 121.8

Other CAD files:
sg_v2/2. 机械结构/外壳/SG-61 v35 上壳.stl
kb84/2. 机械结构/外壳 v1/shell.step
kb84/2. 机械结构/外壳 v1/pillar.step
kb84/2. 机械结构/外壳 v2/shell v2.step
kb84/2. 机械结构/外壳 v1/bottom_plate.f3d
kb84/2. 机械结构/外壳 v1/bottom_plate.step
kb84/2. 机械结构/外壳 v1/bottom_plate.stl
kb84/2. 机械结构/外壳 v1/pillar.f3d
kb84/2. 机械结构/外壳 v1/pillar.stl
kb84/2. 机械结构/外壳 v1/shell.f3d
kb84/2. 机械结构/外壳 v1/shell.stl
kb84/2. 机械结构/外壳 v2/bottom_plate v2.dxf
kb84/2. 机械结构/外壳 v2/bottom_plate v2.stl
kb84/2. 机械结构/外壳 v2/pillar v2.step
kb84/2. 机械结构/外壳 v2/pillar v2.stl
kb84/2. 机械结构/外壳 v2/shell v2.stl
sg_v2/2. 机械结构/外壳/SG-61 v34 底盖.f3z
sg_v2/2. 机械结构/外壳/SG-61 v36 上壳.f3z
sg_v2/2. 机械结构/外壳/SG-61 v46.f3z

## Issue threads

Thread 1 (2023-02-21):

想要购买键盘，是否可以买到

KenshinLam, 2023-02-21:
想要购买这款键盘，是否可以买到？麻烦答复

zsdycs, 2023-02-21:
可以的，而且由于是手工焊接制作的，所以难免有不完美的地方，做工有别于市面上的成品键盘。
而且自己 DIY 费用会比较高，所以我不建议找我购买（主要是我怕这费力不讨好），自己做会更有成就感。我可以提供制作的支持，有什么问题都可以找我。

SG_V2 的物料成本大概是这样的：

- 光固化 3D 打印上下外壳 100
- 电路板 5 块板子起订共 90
- 主控 32u4 大概 30
- 电阻、电容、晶振、静电保护、ffc 排线、ffc 连接器、USB 口和 LED 灯 大概 60
- 上下盖连接磁铁 3mm*3mm 共 114 颗 20
- 机械轴 61 颗价格在 70 ~ 260 之间取决于好坏
- 键帽，照片上白绿颜色的键帽 69
- USB 副板嘉立创可以免费打

以上合计 440

焊接大概要 4 ~6 个小时

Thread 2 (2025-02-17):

About  Publication of PickAndPlace file

Neosky123, 2025-02-17:
Nice to meet you, I am learning about DIY-keyboard.
I have found your project by searching for a model of 32U4 MCU soldered directly to the keyboard.
sg_v1's component size is small and I would like to use JLC-PCB's mounting service.
Can you publish a PickAndPlace with the component placement diagram and angles?

zsdycs, 2025-02-23:
没用过JLC的SMT贴片，我的键盘都是手动焊接的，我认为在电路板文件夹下的Gerber文件和BOM文件可以用于SMT贴片，或者是直接打开工程，我刚刚开源了[PCB工程](https://u.lceda.cn/

)

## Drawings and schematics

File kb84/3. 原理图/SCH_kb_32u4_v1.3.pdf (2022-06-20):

# DC-DC 降压 3.3V 输出(可选)

# USB接口

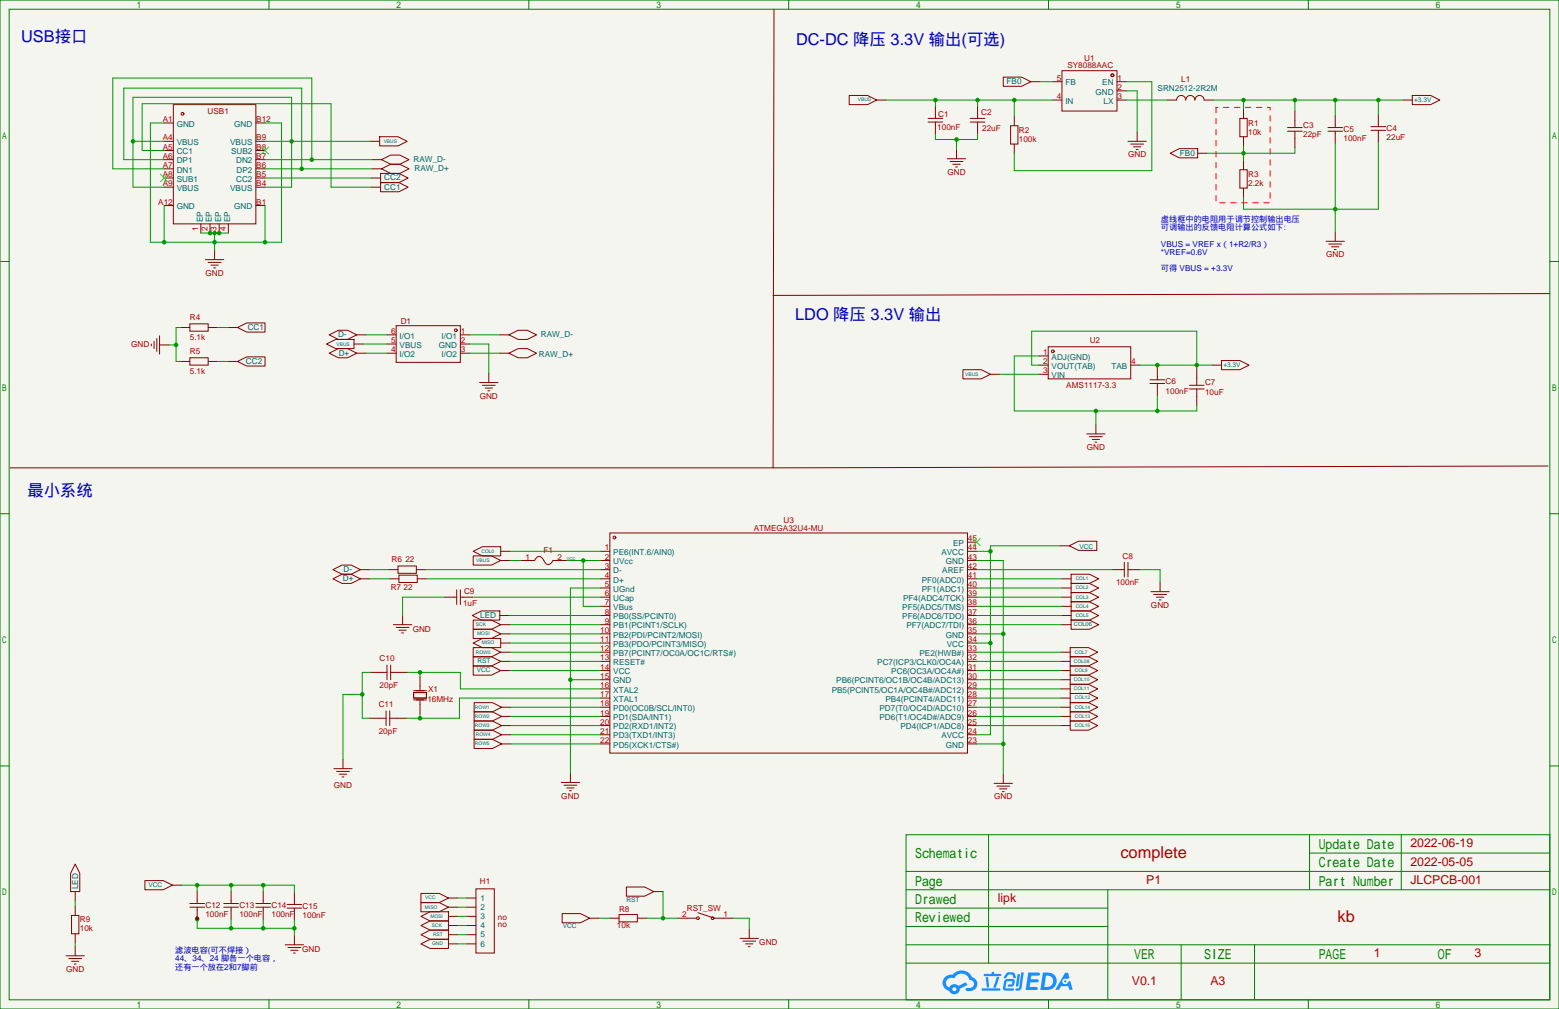
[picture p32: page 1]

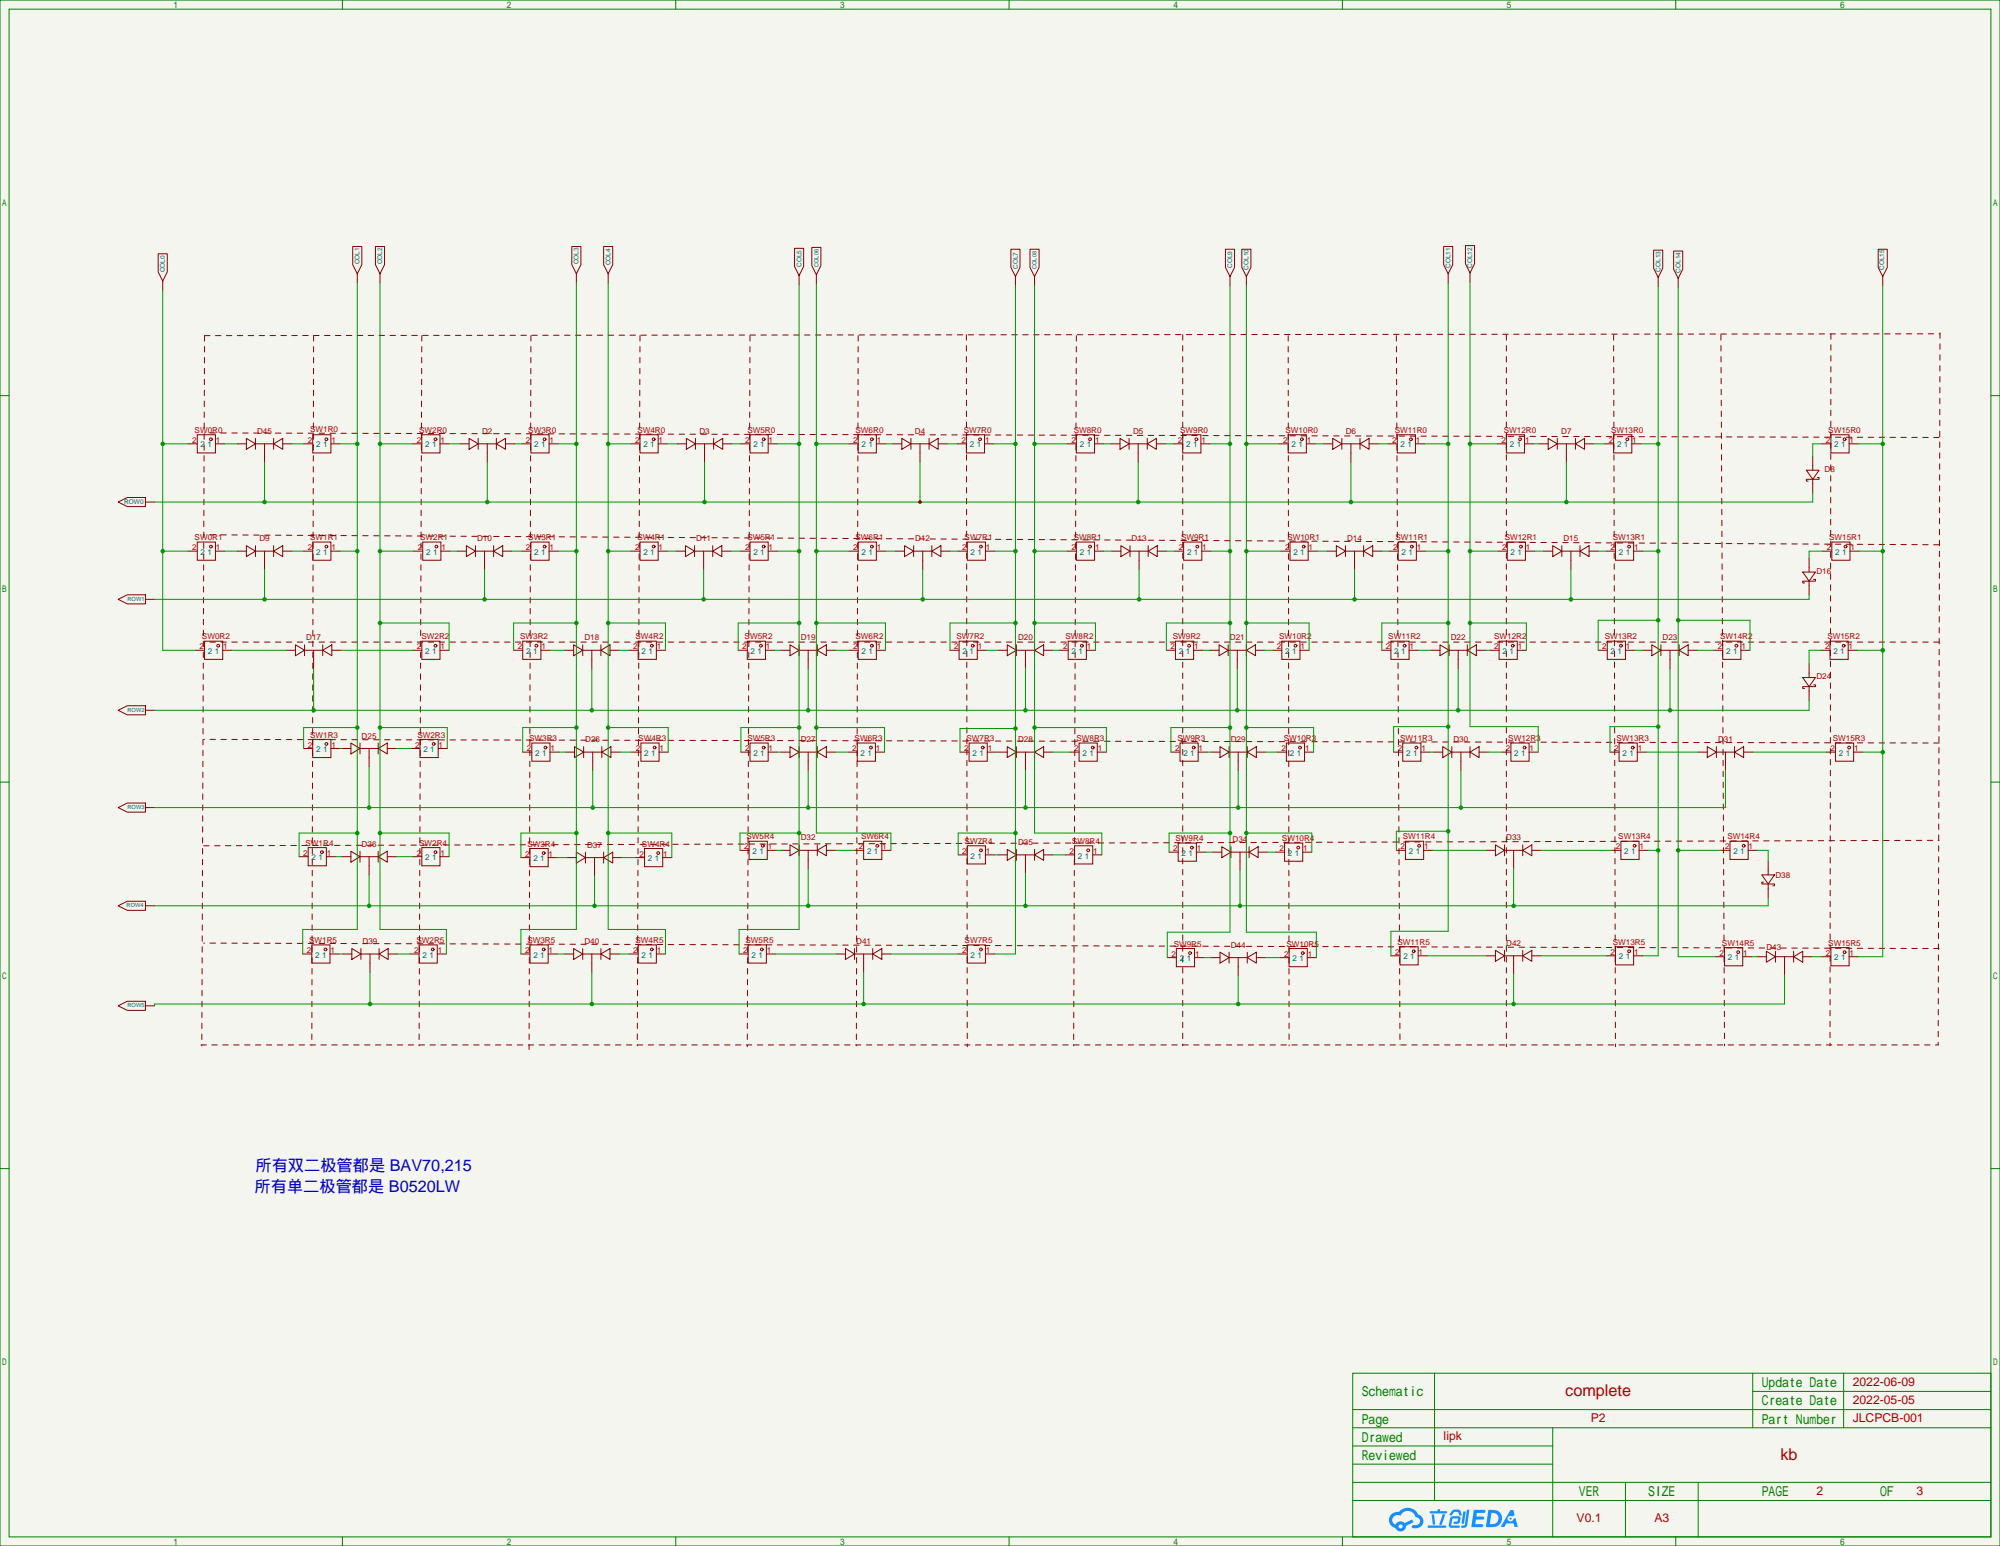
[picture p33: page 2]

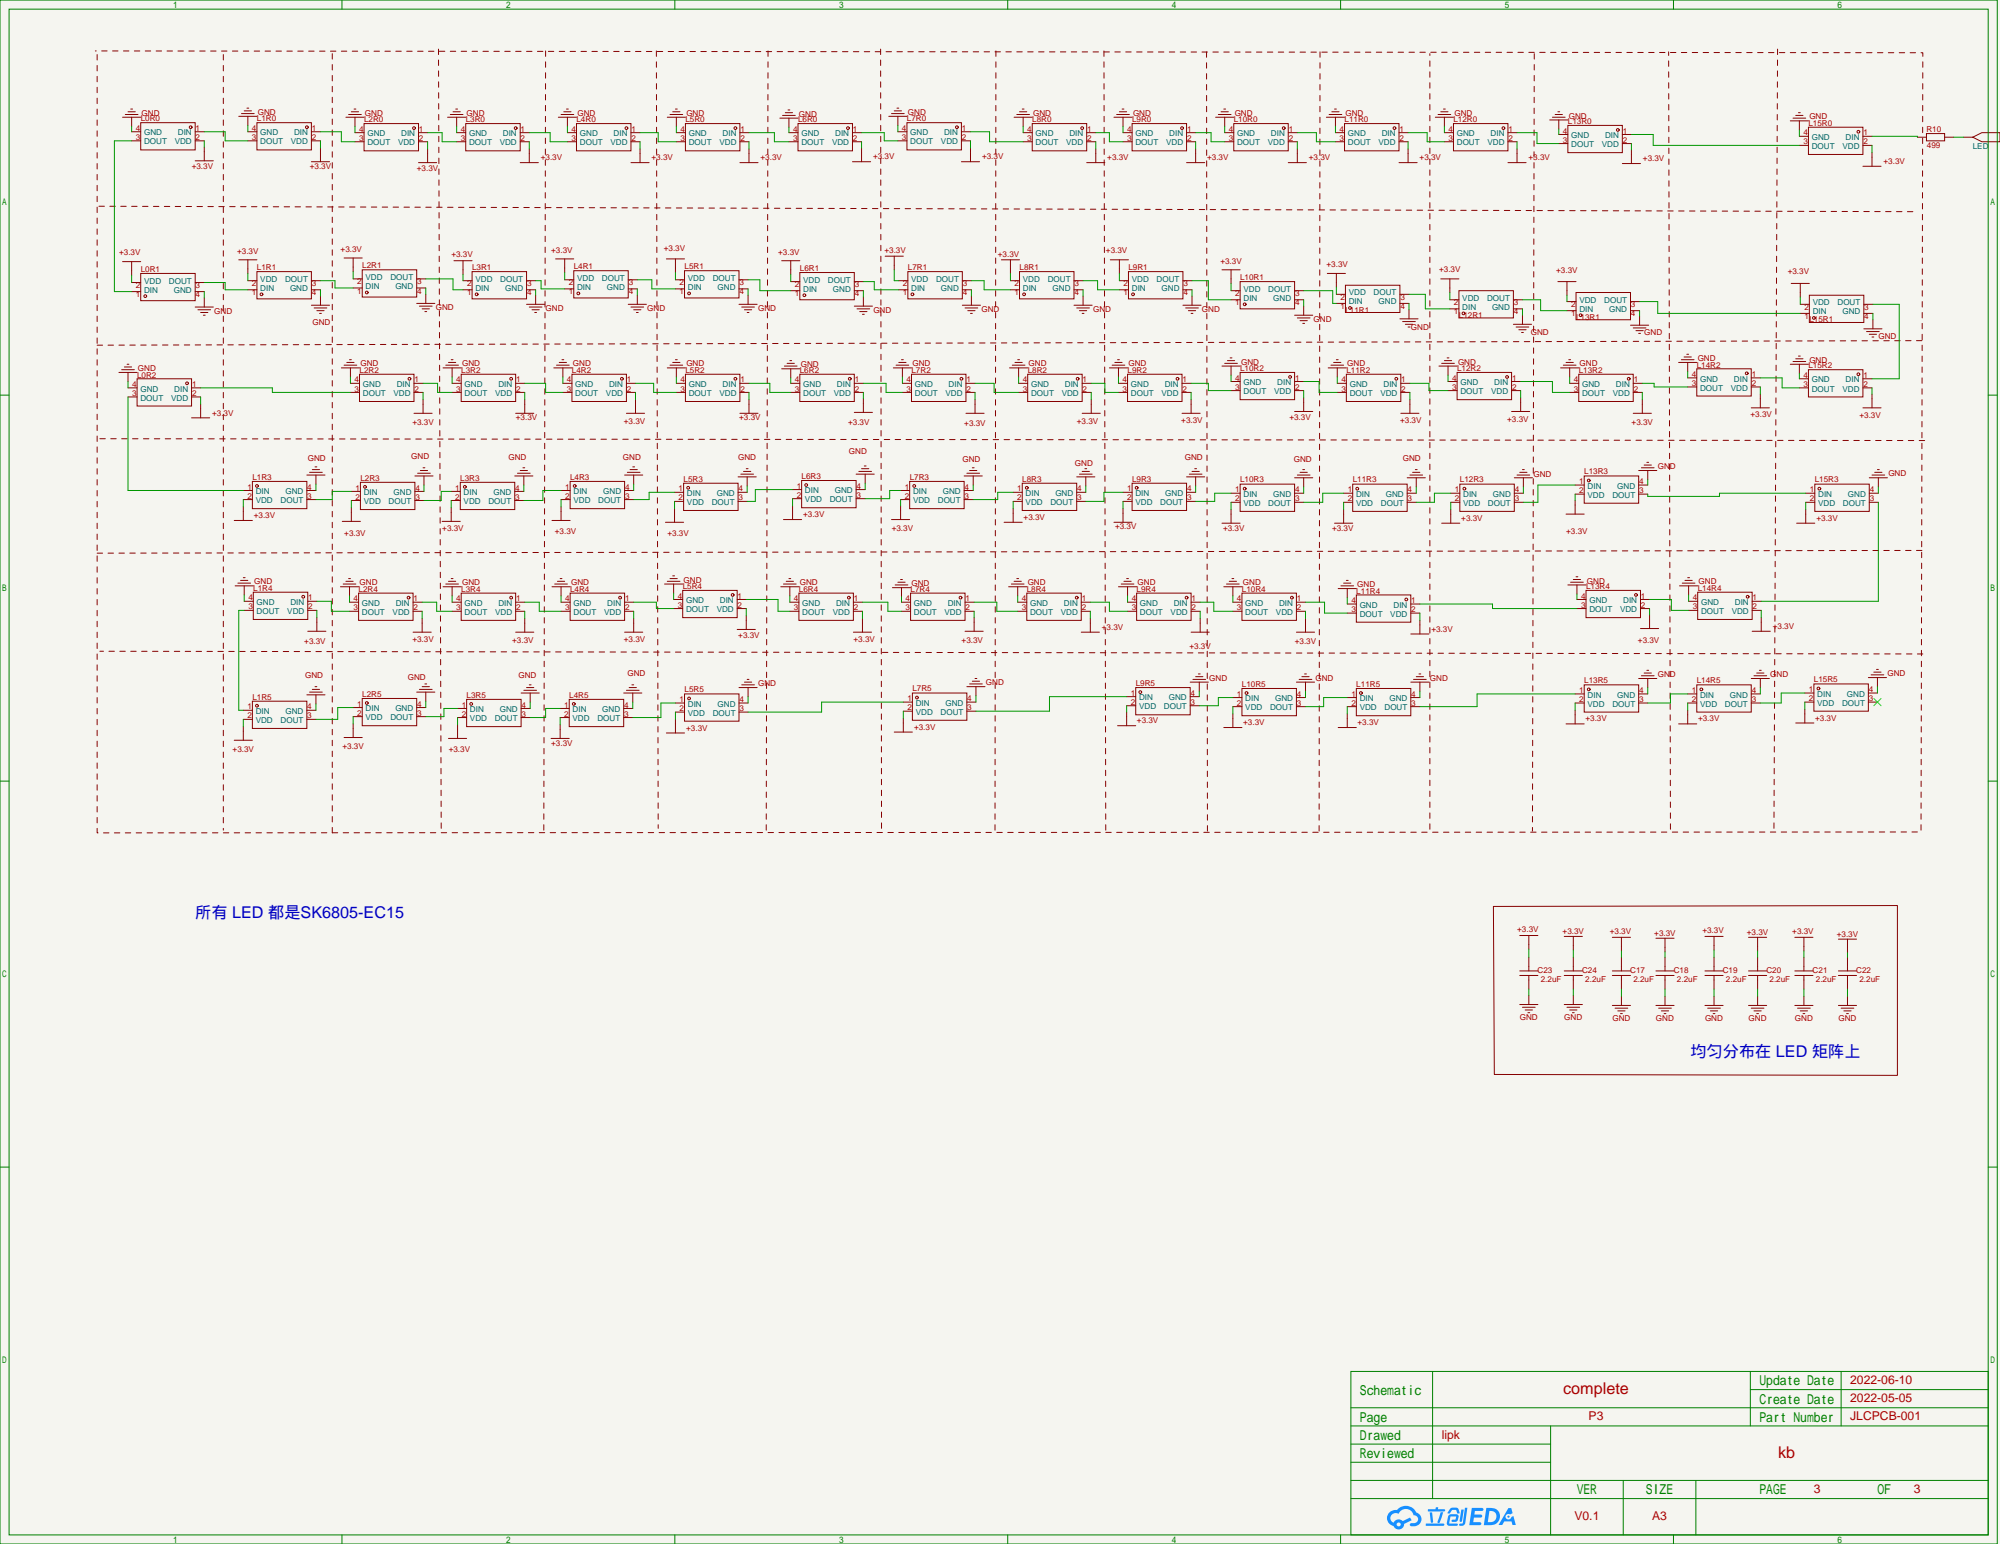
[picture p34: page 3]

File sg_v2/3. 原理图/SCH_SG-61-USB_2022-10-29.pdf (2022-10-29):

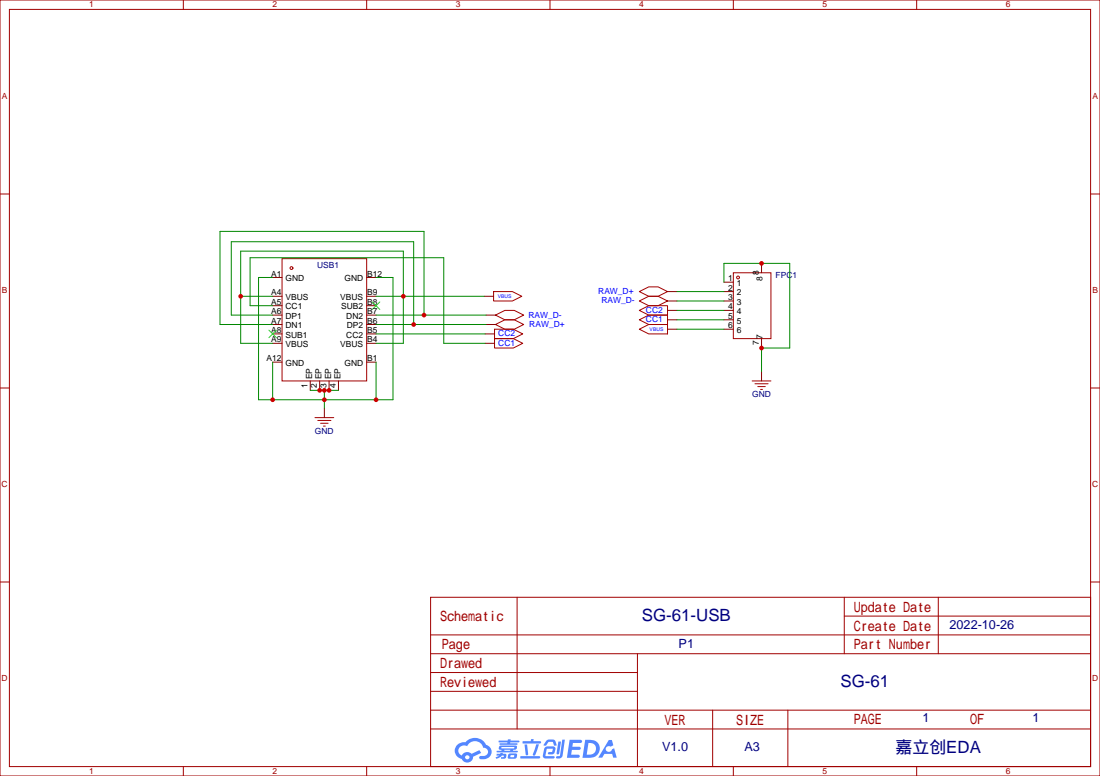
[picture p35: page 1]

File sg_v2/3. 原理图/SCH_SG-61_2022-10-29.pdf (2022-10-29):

接口

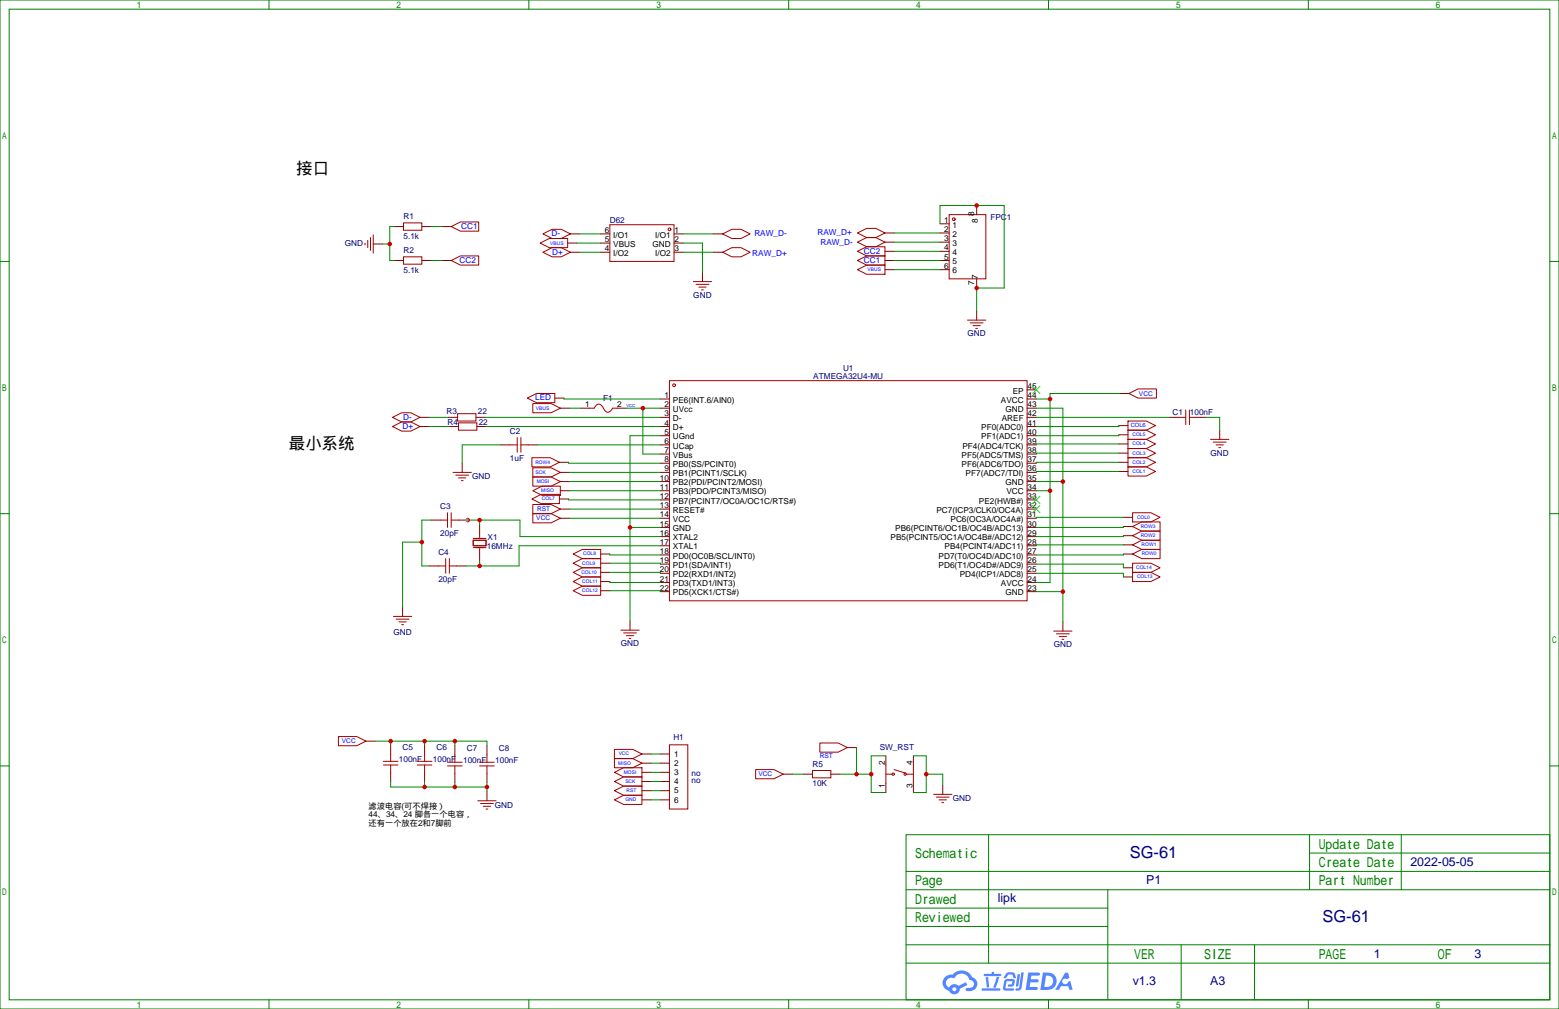
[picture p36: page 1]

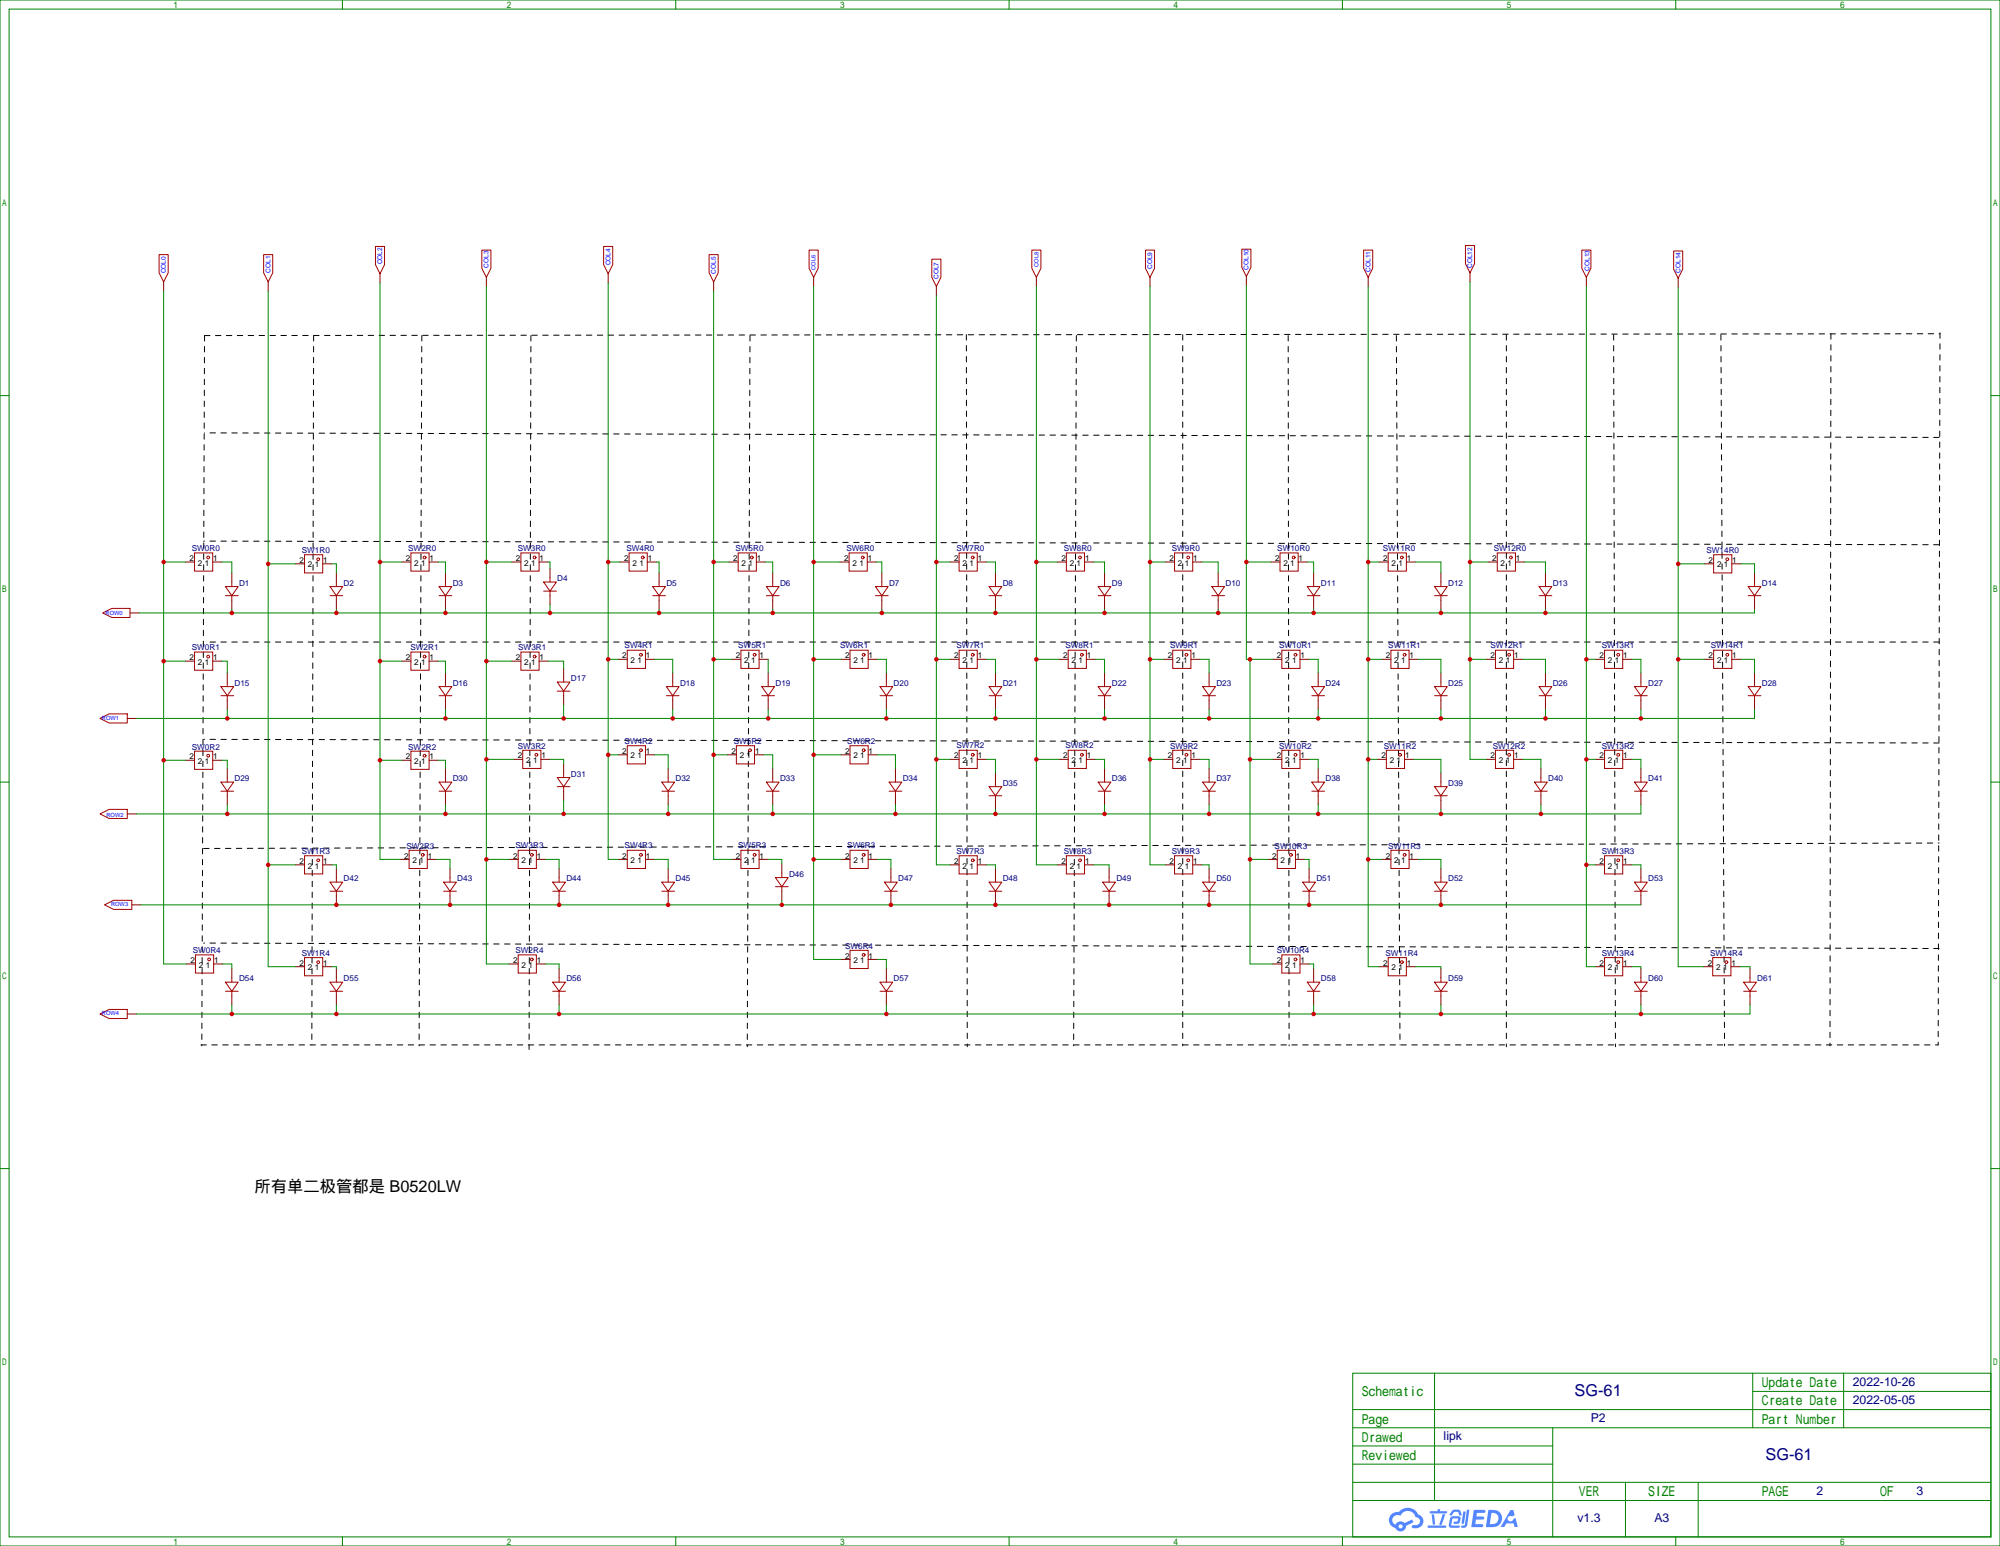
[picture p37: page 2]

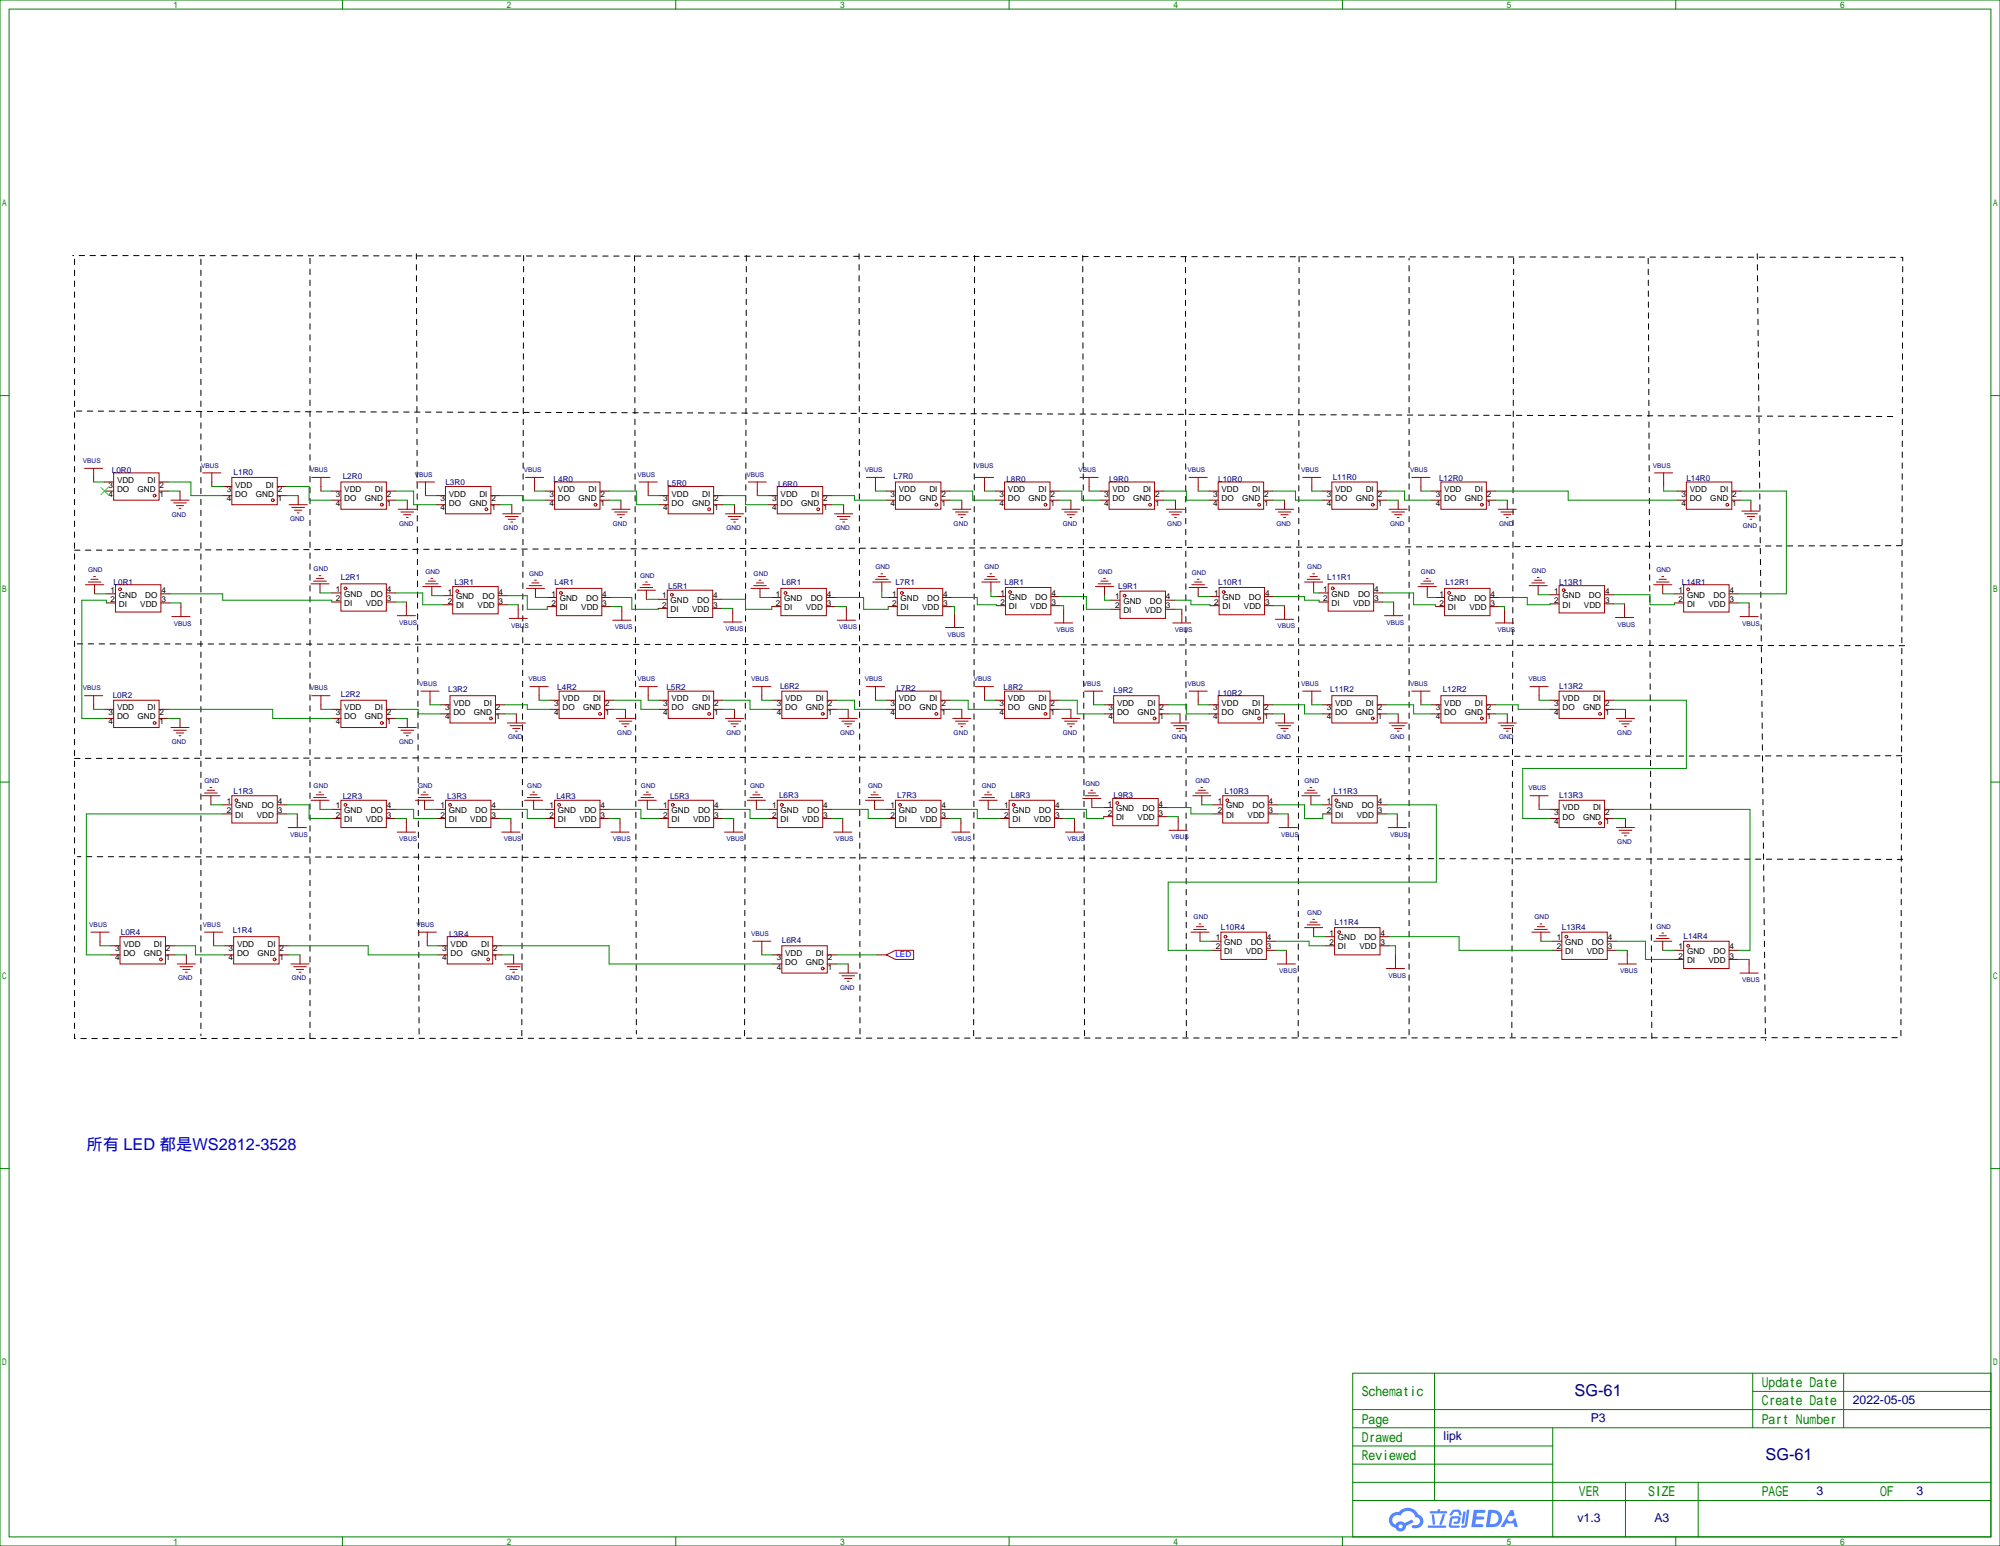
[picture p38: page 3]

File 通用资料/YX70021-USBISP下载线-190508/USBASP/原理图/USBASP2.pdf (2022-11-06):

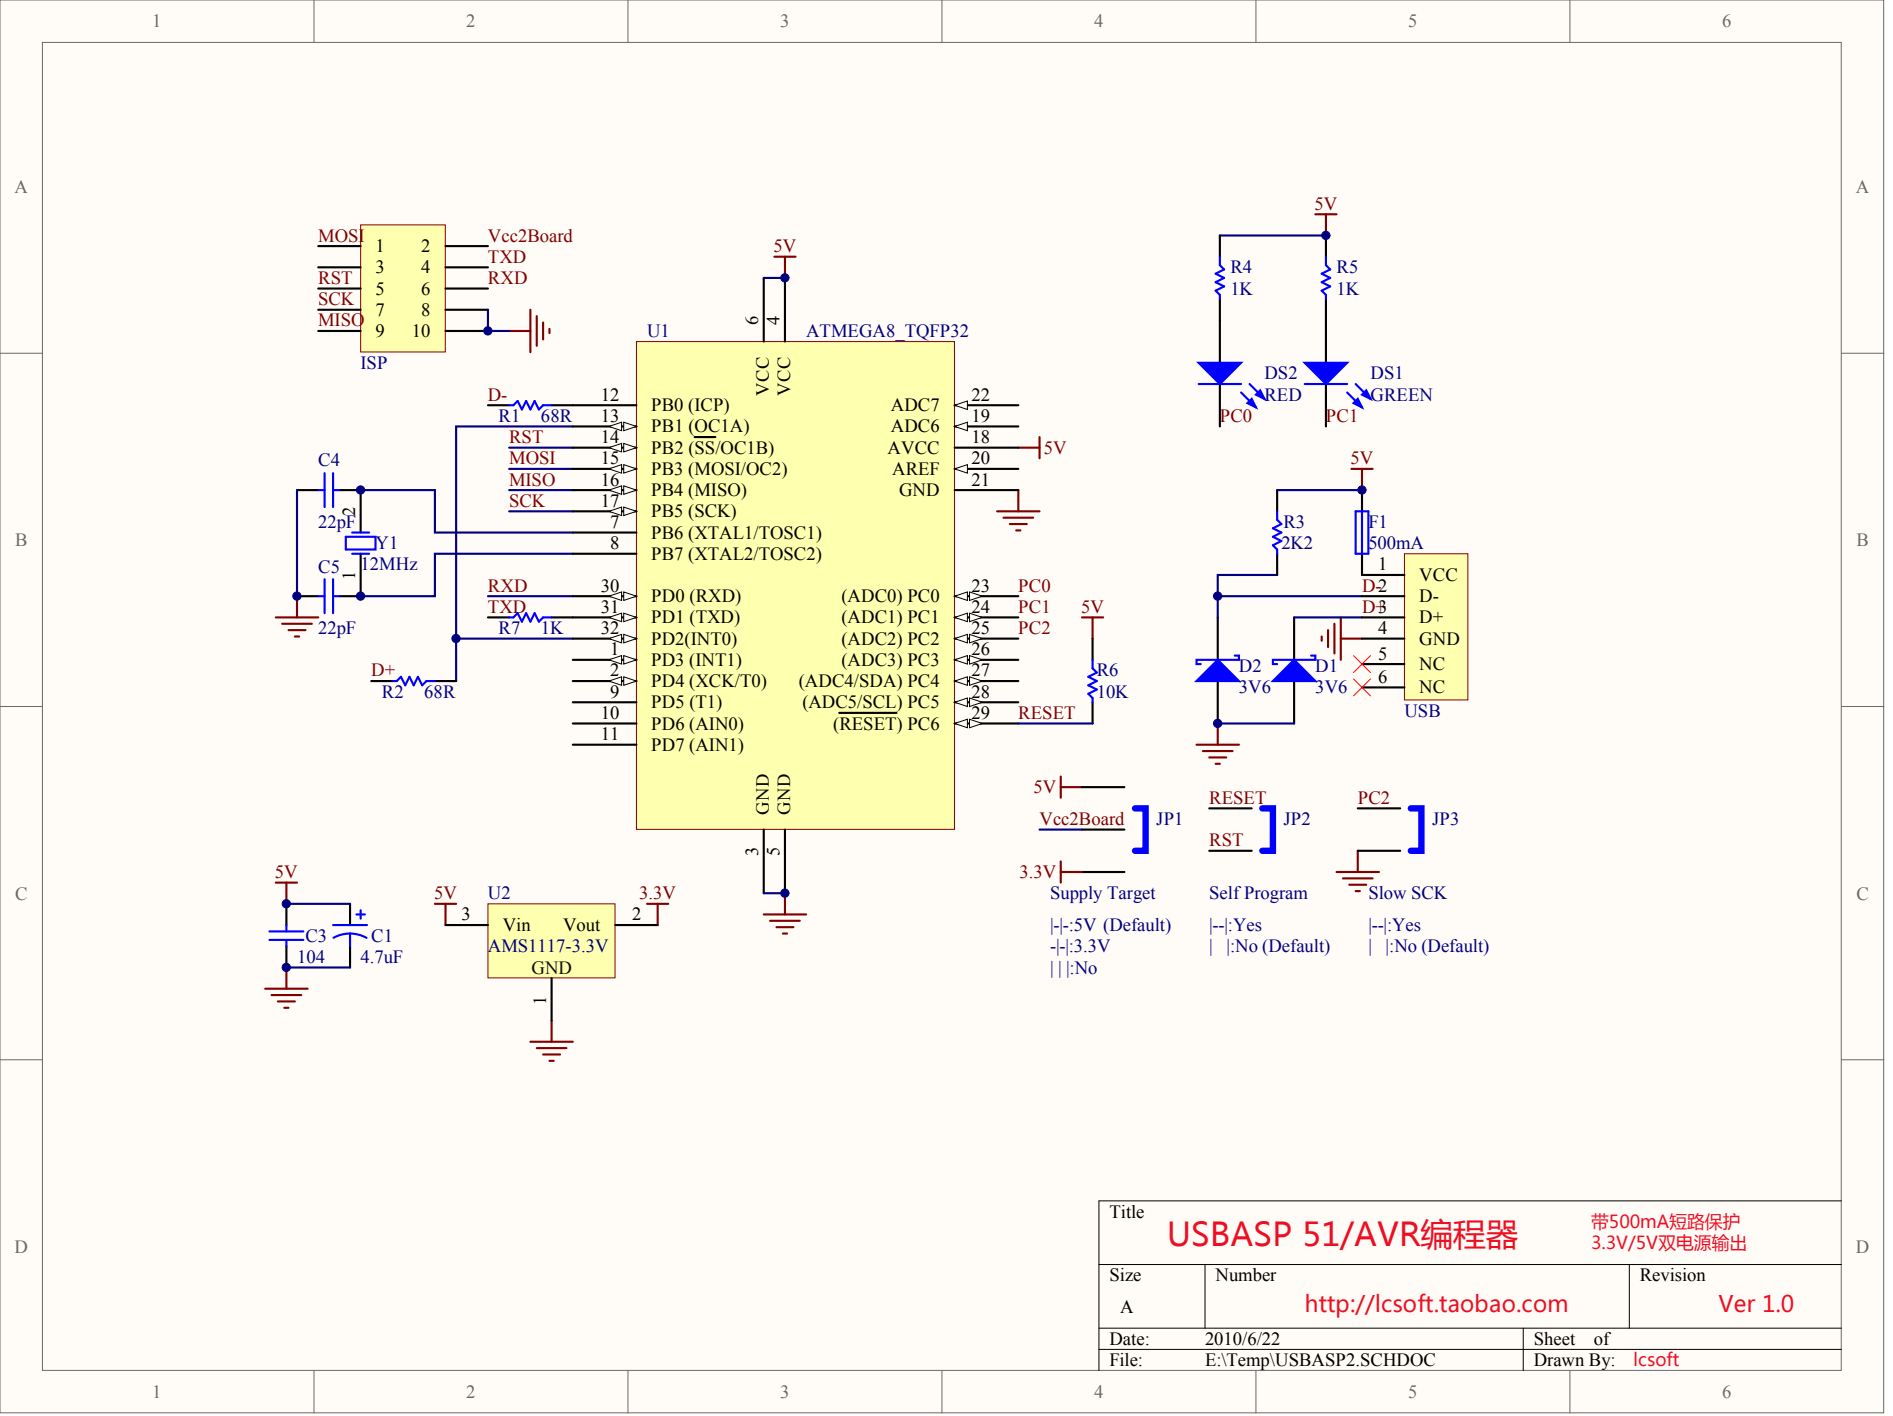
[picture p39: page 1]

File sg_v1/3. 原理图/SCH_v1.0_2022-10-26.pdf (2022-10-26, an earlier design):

# USB接口

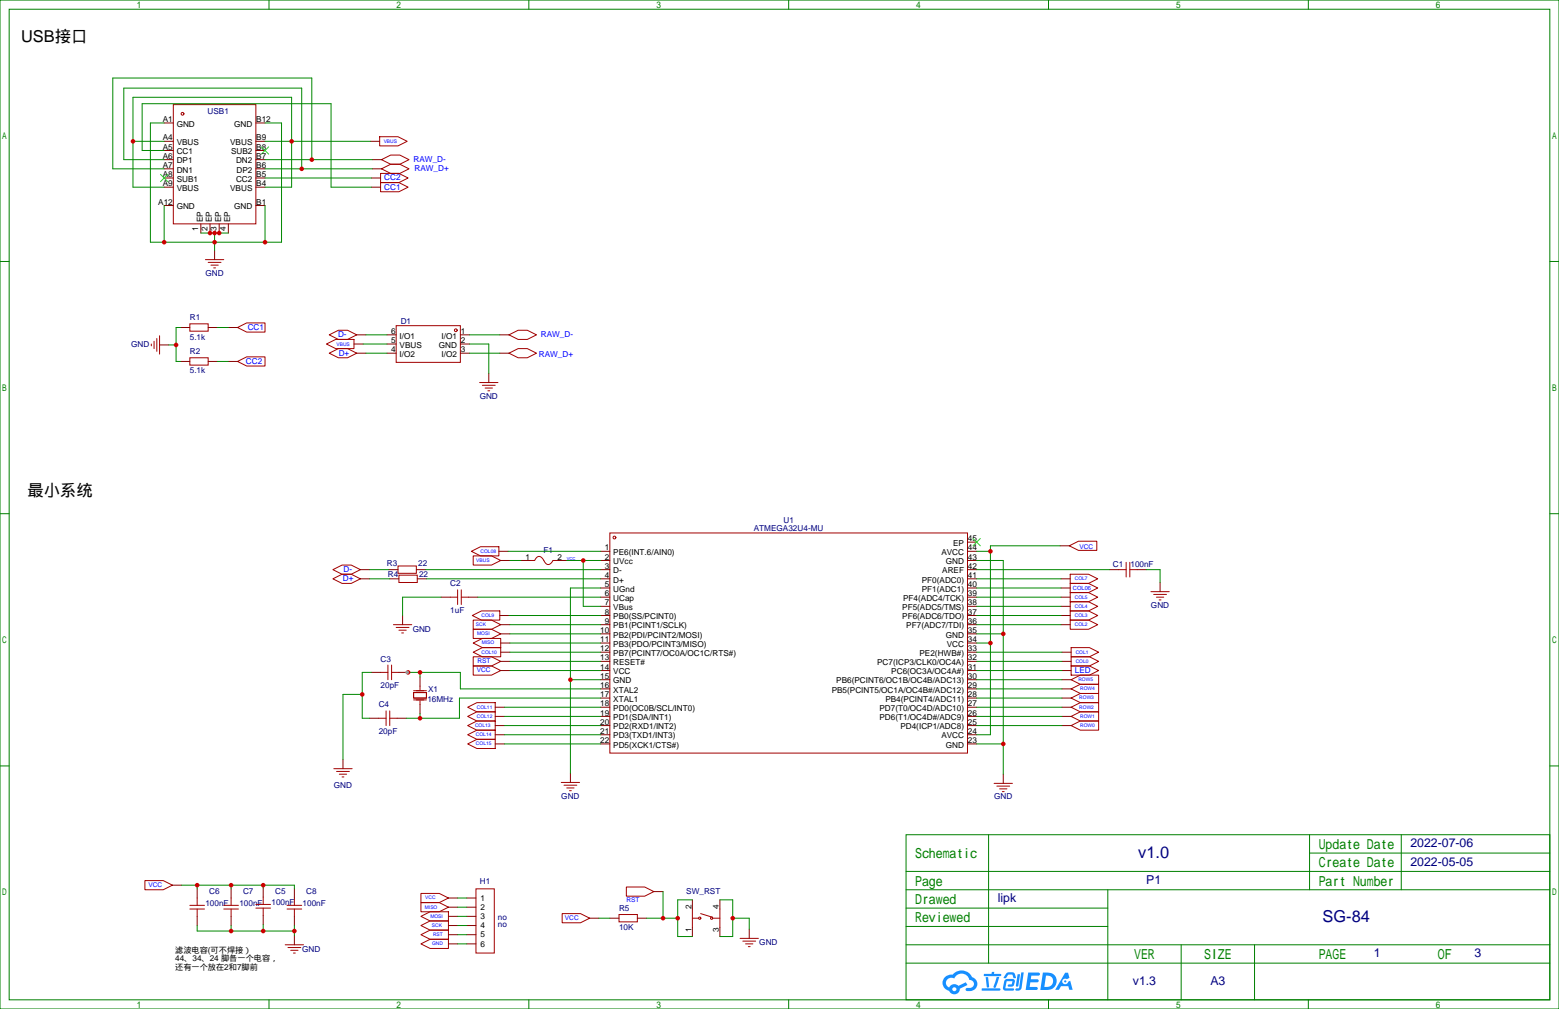
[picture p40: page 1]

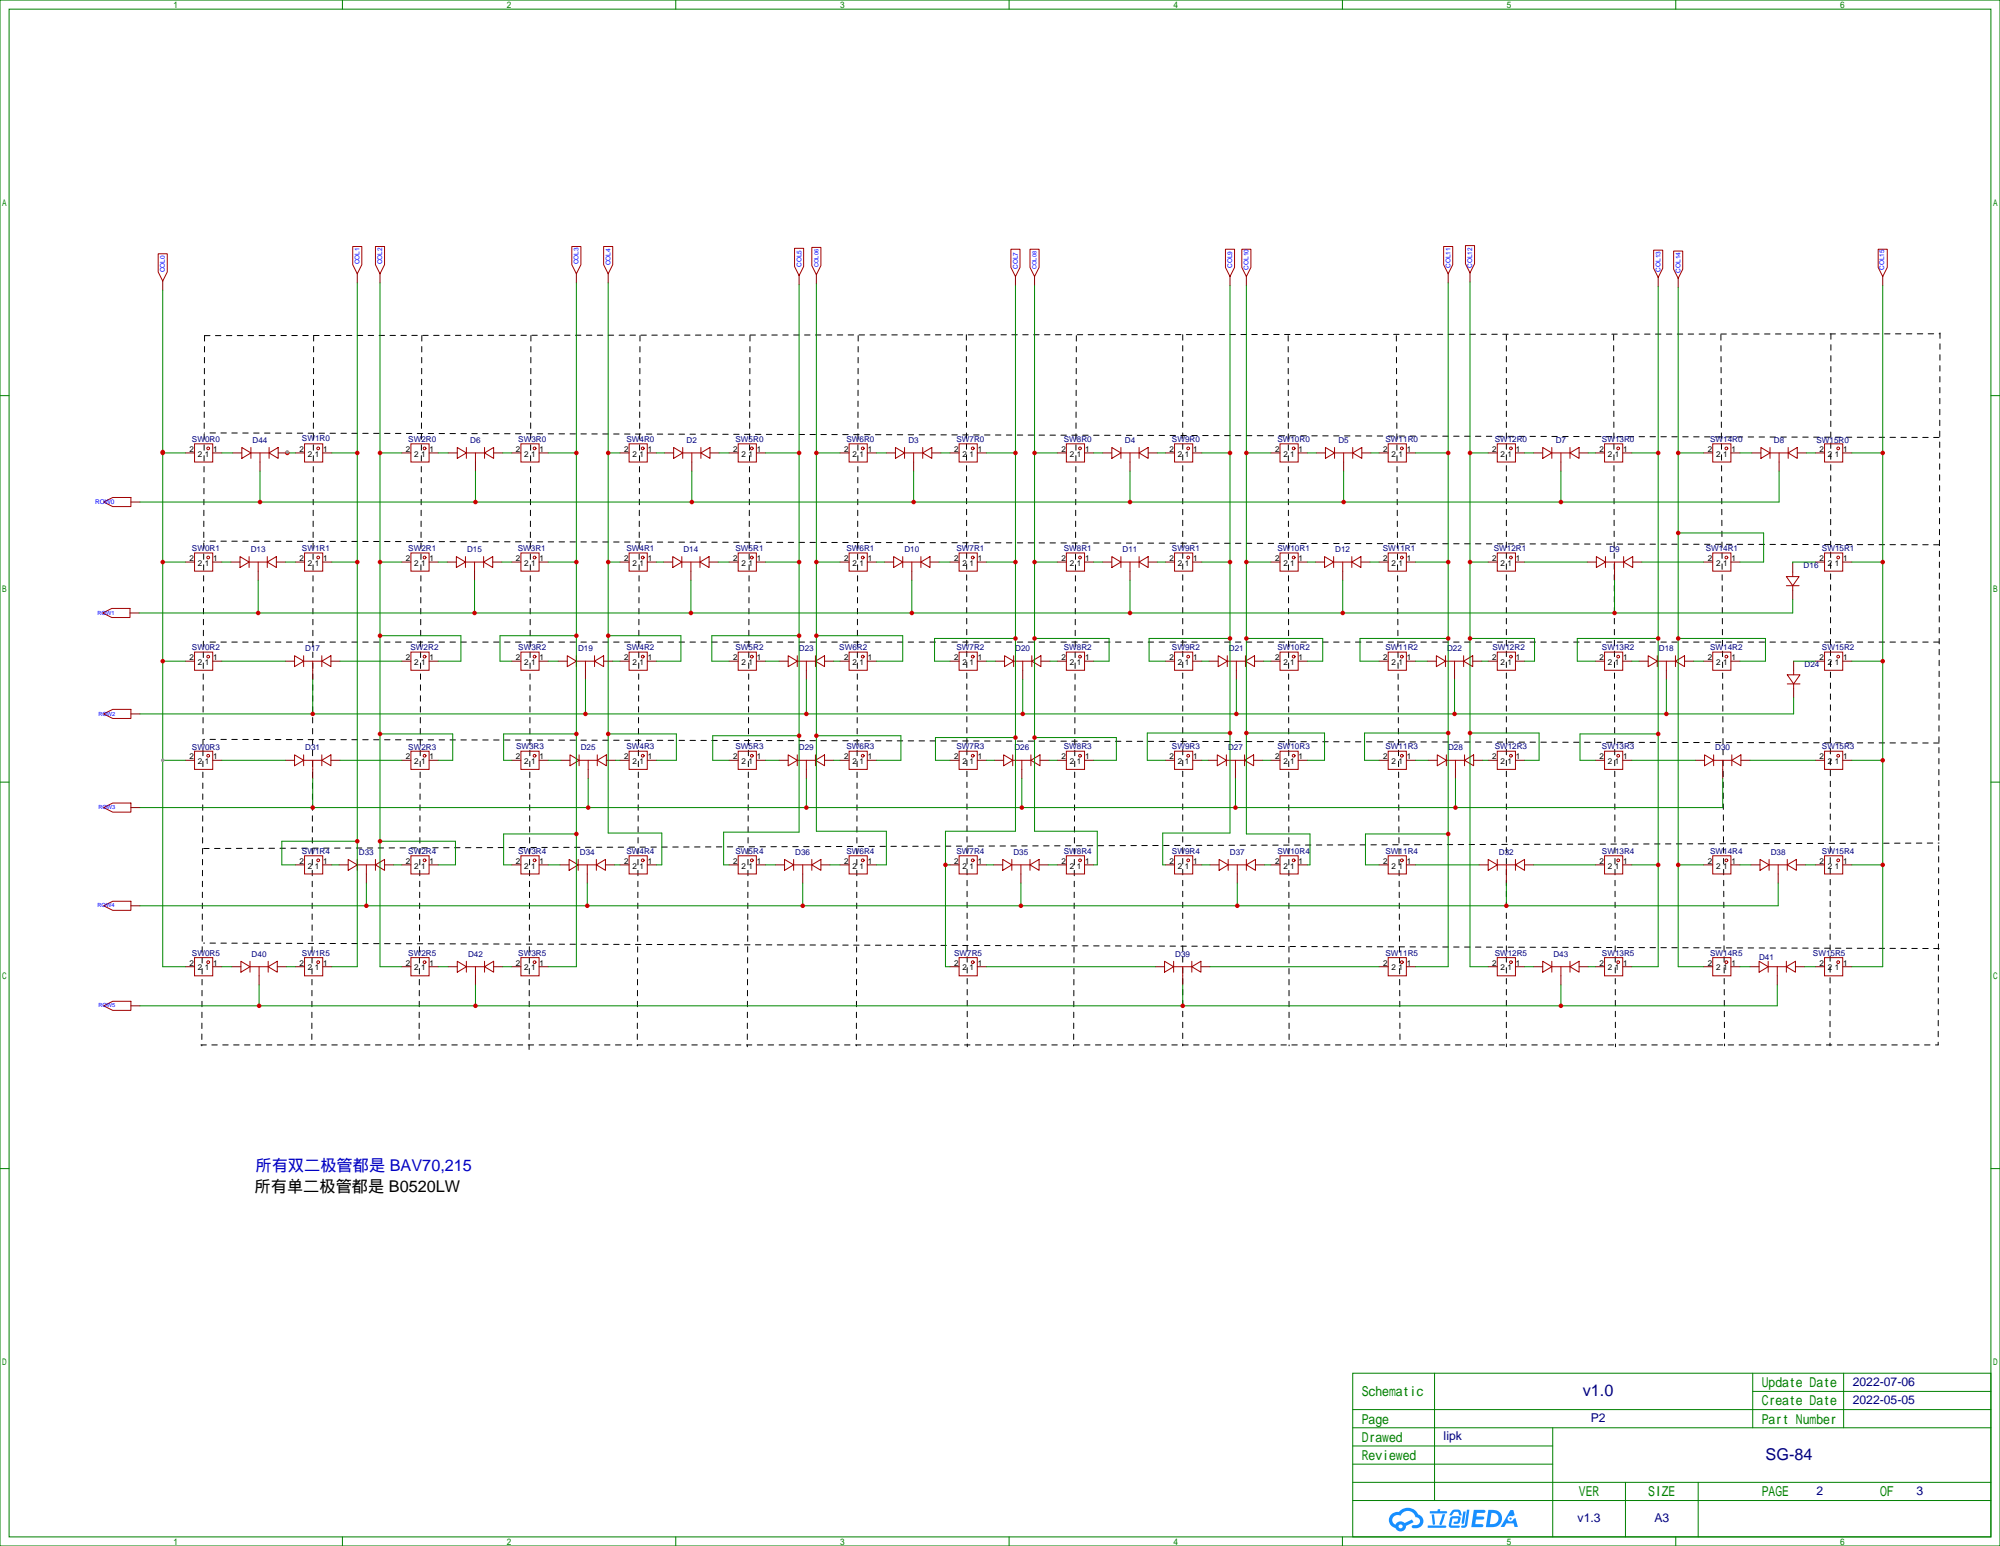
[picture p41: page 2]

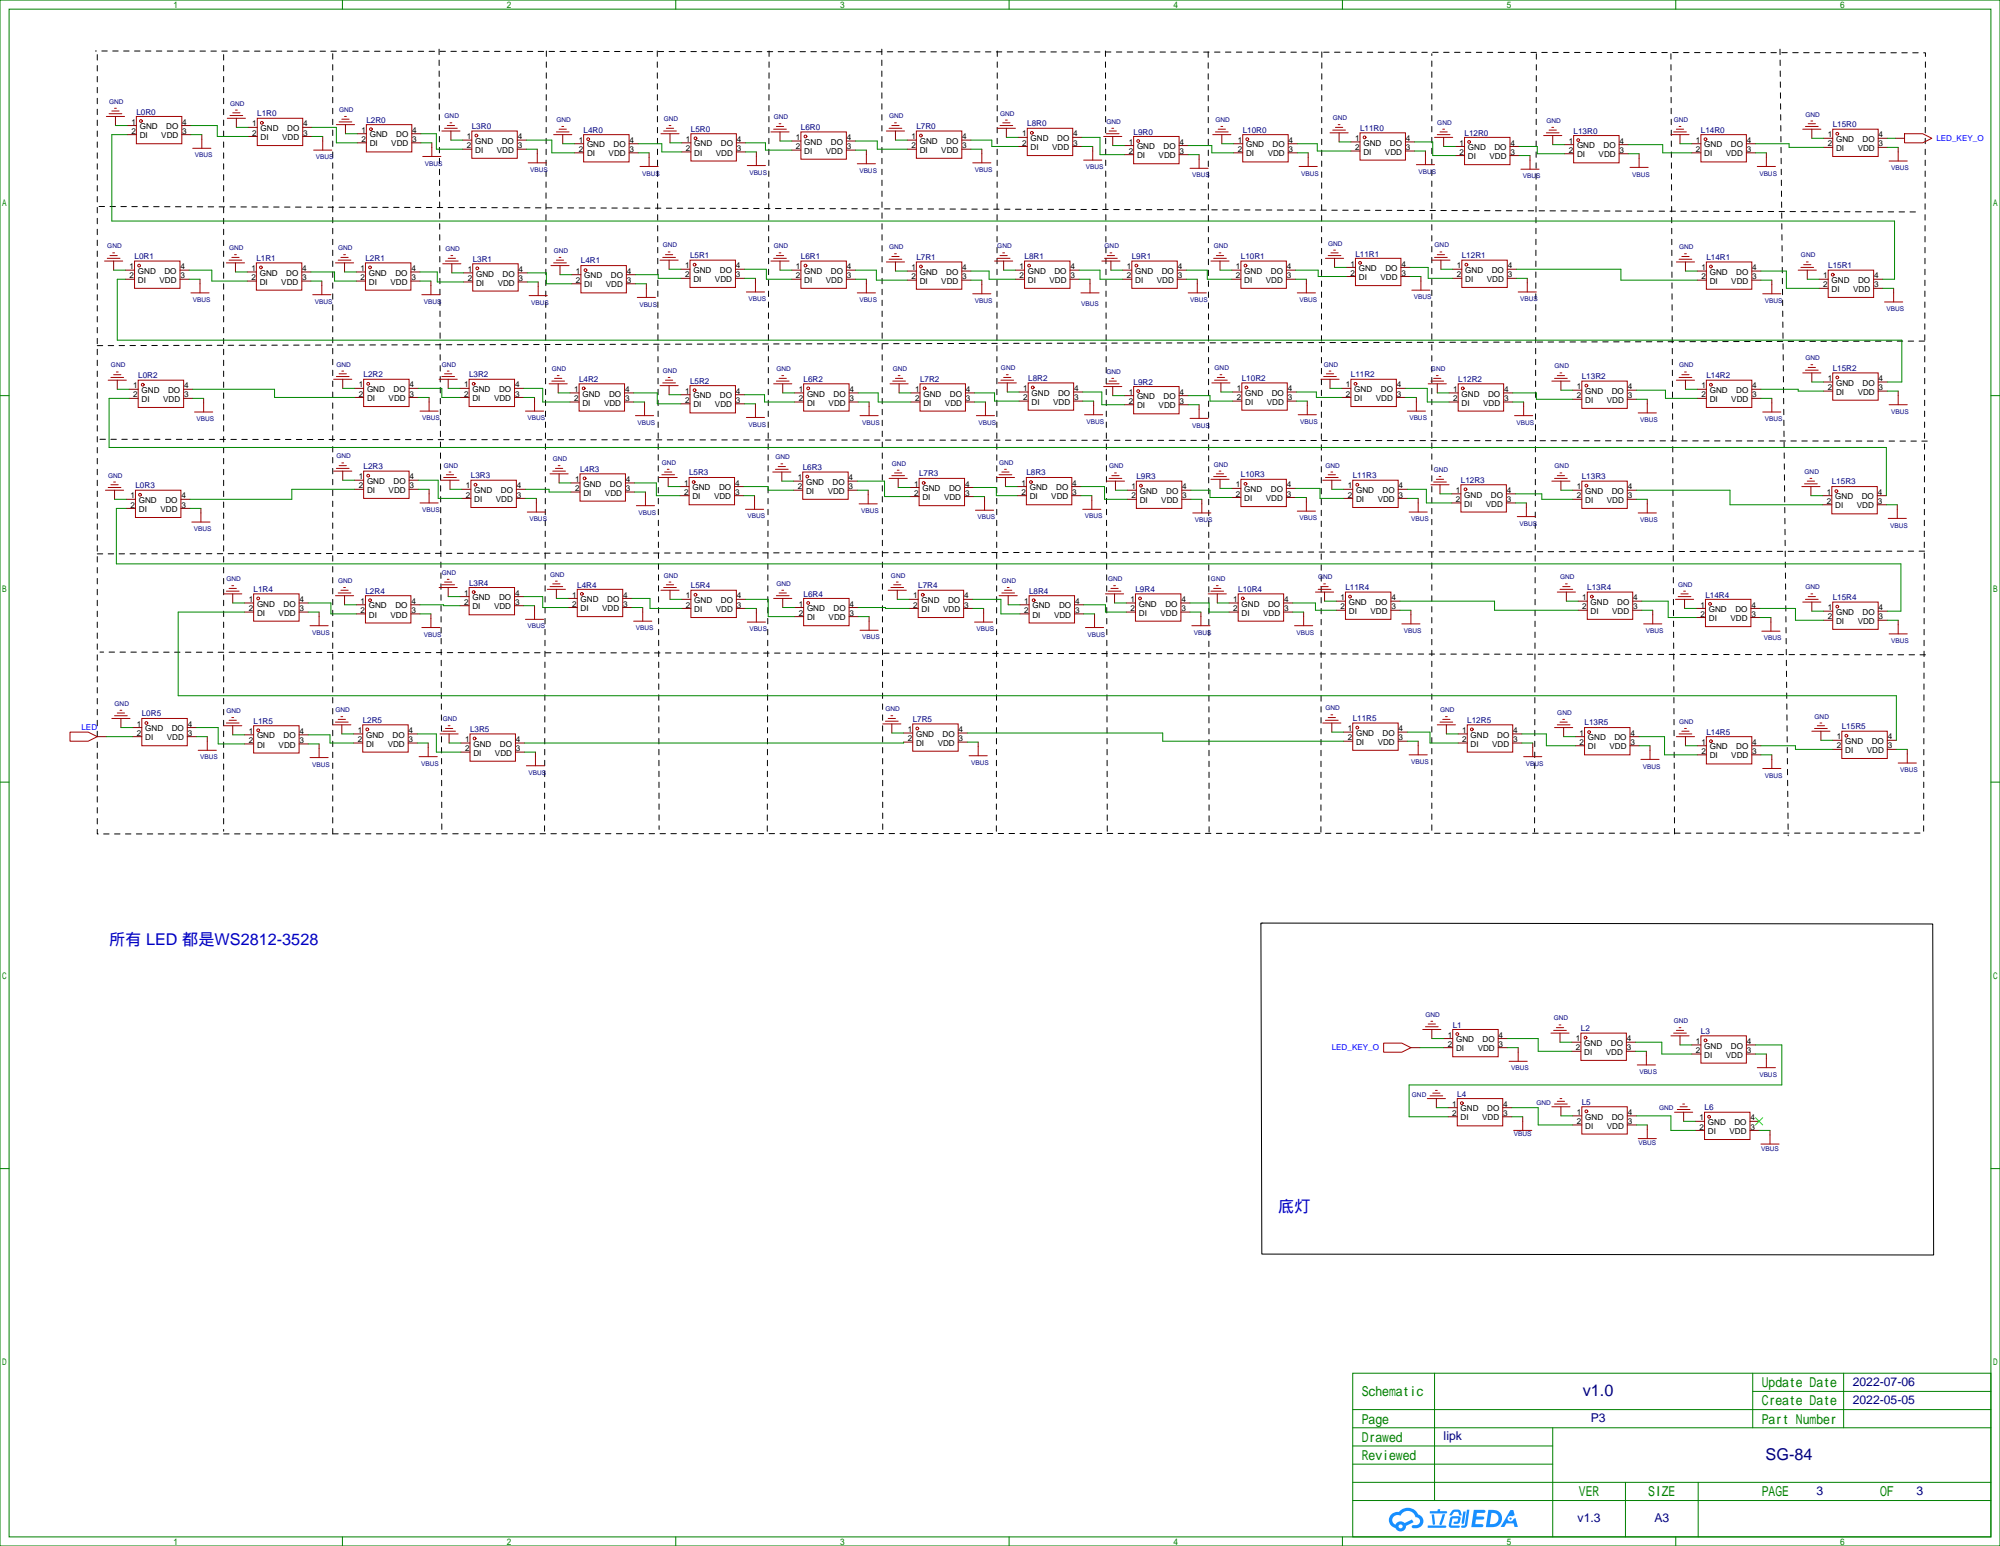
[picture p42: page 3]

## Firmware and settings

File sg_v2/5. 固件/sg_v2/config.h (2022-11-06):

#pragma once

#include "config_common.h"

/* USB 设备描述符参数 */
#define VENDOR_ID    0x3385
#define PRODUCT_ID   0x0001
#define DEVICE_VER   0x0001
// 制造商
#define MANUFACTURER Lipk
// 产品名称
#define PRODUCT Lipk shiguang 61
// 描述
// #define DESCRIPTION Lipk_shiguang

/* key matrix size */
#define MATRIX_ROWS 5
#define MATRIX_COLS 15

/* key matrix pins */
// 32u4
#define MATRIX_ROW_PINS { \
                            D7, /* ROW0 */ \
                            B4, /* ROW1 */ \
                            B5, /* ROW2 */ \
                            B6, /* ROW3 */ \
                            B0 /* ROW4 */ \
                        }
#define MATRIX_COL_PINS { \
                            C6, /* COL0 */  \
                            F7, /* COL1 */  \
                            F6, /* COL2 */  \
                            F5, /* COL3 */  \
                            F4, /* COL4 */  \
                            F1, /* COL5 */  \
                            F0, /* COL6 */  \
                            B7, /* COL7 */  \
                            D0, /* COL8 */  \
                            D1, /* COL9 */  \
                            D2, /* COL10 */ \
                            D3, /* COL11 */ \
                            D5, /* COL12 */ \
                            D4, /* COL13 */ \
                            D6  /* COL14 */ \
                        }

/* COL2ROW 或 ROW2COL */
#define DIODE_DIRECTION COL2ROW

/* 如果不需要去抖动，则设置为 0 */
#define DEBOUNCE 5

#if RGB_MATRIX_ENABLE
    #define RGB_DI_PIN E6
    #define DRIVER_LED_TOTAL 61
    #define RGB_MATRIX_KEYPRESSES // 对按键做出反应
    //#define RGB_MATRIX_KEYRELEASES // 对按键释放做出反应（而不是按键）
    #define RGB_MATRIX_FRAMEBUFFER_EFFECTS
    #define RGB_DISABLE_TIMEOUT 0 // 等待 RGB 自动关闭的毫秒数
    #define RGB_DISABLE_AFTER_TIMEOUT 0 // OBSOLETE：等待禁用效果的刻度数
    #define RGB_DISABLE_WHEN_USB_SUSPENDED true // 暂停时关闭效果
    #define RGB_MATRIX_LED_FLUSH_LIMIT 16
    #define RGB_MATRIX_MAXIMUM_BRIGHTNESS 180 // 将 LED 的最大亮度限制为 255 中的 200。如果未定义，最大亮度设置为 255
    #define RGB_MATRIX_STARTUP_MODE RGB_MATRIX_CYCLE_LEFT_RIGHT // 设置默认模式
    #define RGB_MATRIX_STARTUP_HUE 200 // 如果未设置任何色调值，则设置默认色调值
    #define RGB_MATRIX_STARTUP_SAT 255 // 如果未设置任何饱和值，则设置默认饱和值
    #define RGB_MATRIX_STARTUP_VAL RGB_MATRIX_MAXIMUM_BRIGHTNESS
    #define RGB_MATRIX_STARTUP_SPD 127
    #define RGB_MATRIX_CENTER {119,  26} // RGB 矩阵中心，“Y” 键
    // 开启灯光效果 {
    // #define ENABLE_RGB_MATRIX_ALPHAS_MODS
    // #define ENABLE_RGB_MATRIX_GRADIENT_UP_DOWN
    // #define ENABLE_RGB_MATRIX_GRADIENT_LEFT_RIGHT
    // #define ENABLE_RGB_MATRIX_BREATHING
    // #define ENABLE_RGB_MATRIX_BAND_SAT
    // #define ENABLE_RGB_MATRIX_BAND_VAL
    // #define ENABLE_RGB_MATRIX_BAND_PINWHEEL_SAT
    // #define ENABLE_RGB_MATRIX_BAND_PINWHEEL_VAL
    // #define ENABLE_RGB_MATRIX_BAND_SPIRAL_SAT
    // #define ENABLE_RGB_MATRIX_BAND_SPIRAL_VAL
    // #define ENABLE_RGB_MATRIX_CYCLE_ALL
    #define ENABLE_RGB_MATRIX_CYCLE_LEFT_RIGHT
    // #define ENABLE_RGB_MATRIX_CYCLE_UP_DOWN
    // #define ENABLE_RGB_MATRIX_RAINBOW_MOVING_CHEVRON
    // #define ENABLE_RGB_MATRIX_CYCLE_OUT_IN
    // #define ENABLE_RGB_MATRIX_CYCLE_OUT_IN_DUAL
    // #define ENABLE_RGB_MATRIX_CYCLE_PINWHEEL
    // #define ENABLE_RGB_MATRIX_CYCLE_SPIRAL
    // #define ENABLE_RGB_MATRIX_DUAL_BEACON
    // #define ENABLE_RGB_MATRIX_RAINBOW_BEACON
    // #define ENABLE_RGB_MATRIX_RAINBOW_PINWHEELS
    // #define ENABLE_RGB_MATRIX_RAINDROPS
    // #define ENABLE_RGB_MATRIX_JELLYBEAN_RAINDROPS
    // #define ENABLE_RGB_MATRIX_HUE_BREATHING
    // #define ENABLE_RGB_MATRIX_HUE_PENDULUM
    // #define ENABLE_RGB_MATRIX_HUE_WAVE
    // #define ENABLE_RGB_MATRIX_PIXEL_FRACTAL
    // #define ENABLE_RGB_MATRIX_PIXEL_FLOW
    // #define ENABLE_RGB_MATRIX_PIXEL_RAIN
    // #define ENABLE_RGB_MATRIX_TYPING_HEATMAP
    // #define ENABLE_RGB_MATRIX_DIGITAL_RAIN
    // #define ENABLE_RGB_MATRIX_SOLID_REACTIVE_SIMPLE
    // #define ENABLE_RGB_MATRIX_SOLID_REACTIVE
    // #define ENABLE_RGB_MATRIX_SOLID_REACTIVE_WIDE
    // #define ENABLE_RGB_MATRIX_SOLID_REACTIVE_MULTIWIDE
    // #define ENABLE_RGB_MATRIX_SOLID_REACTIVE_CROSS
    // #define ENABLE_RGB_MATRIX_SOLID_REACTIVE_MULTICROSS
    // #define ENABLE_RGB_MATRIX_SOLID_REACTIVE_NEXUS
    // #define ENABLE_RGB_MATRIX_SOLID_REACTIVE_MULTINEXUS
    // #define ENABLE_RGB_MATRIX_SPLASH
    // #define ENABLE_RGB_MATRIX_MULTISPLASH
    // #define ENABLE_RGB_MATRIX_SOLID_SPLASH
    // #define ENABLE_RGB_MATRIX_SOLID_MULTISPLASH
    // 开启灯光效果 }
    // #define RGB_MATRIX_DISABLE_KEYCODES // 通过键码禁用对 rgb 矩阵的控制（必须使用代码功能来控制该功能）
#endif

// #define LOCKING_SUPPORT_ENABLE // 机械锁定支持。 在键盘映射中使用 KC_LCAP、KC_LNUM 或 KC_LSCR

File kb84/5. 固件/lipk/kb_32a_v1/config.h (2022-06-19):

#pragma once

#include "config_common.h"

/* USB 设备描述符参数 */
#define VENDOR_ID       0x3384
#define PRODUCT_ID      0x0001
#define DEVICE_VER      0x0001
// 制造商
#define MANUFACTURER    lipk.org
// 产品名称
#define PRODUCT         Lipk Keyboard 1.1 via_32a
// 描述
#define DESCRIPTION         Lipk Keyboard 1.1 via_32a

/* key matrix size */
#define MATRIX_ROWS 6
#define MATRIX_COLS 14

/* key matrix pins */
// 32a
#define MATRIX_ROW_PINS { A1, A2, A3, A4, A5, A6, }
#define MATRIX_COL_PINS { D0, C0, D1, D5, D6, D7, C1, C2, C3, C4, C5, C6, C7, }
#define UNUSED_PINS

/* COL2ROW 或 ROW2COL */
#define DIODE_DIRECTION COL2ROW

/* 如果不需要去抖动，则设置为 0 */
#define DEBOUNCE 5

// 32A 不支持全键无冲
// #define FORCE_NKRO

#define RGB_MATRIX_CENTER { 89,  38 } // RGB 矩阵中心，“H” 键

#if RGBLIGHT_ENABLE
    #define RGB_DI_PIN A7
    #define RGBLED_NUM 84
    #define RGBLIGHT_ANIMATIONS
    #define RGBLIGHT_LIMIT_VAL 255
#endif

#if RGB_MATRIX_ENABLE
    #define RGB_DI_PIN A7
    #define DRIVER_LED_TOTAL 84
    #define RGB_MATRIX_KEYPRESSES // 对按键做出反应
    //#define RGB_MATRIX_KEYRELEASES // 对按键释放做出反应（而不是按键）
    #define RGB_MATRIX_FRAMEBUFFER_EFFECTS
    #define RGB_DISABLE_TIMEOUT 0 // 等待 RGB 自动关闭的毫秒数
    #define RGB_DISABLE_AFTER_TIMEOUT 0 // OBSOLETE：等待禁用效果的刻度数
    #define RGB_DISABLE_WHEN_USB_SUSPENDED true // 暂停时关闭效果
    #define RGB_MATRIX_MAXIMUM_BRIGHTNESS 255 // 将 LED 的最大亮度限制为 255 中的 255。如果未定义，最大亮度设置为 255
    #define RGB_MATRIX_STARTUP_MODE RGB_MATRIX_RAINBOW_MOVING_CHEVRON // 设置默认模式，如果没有设置
    #define RGB_MATRIX_STARTUP_HUE 142 // 200度
    #define RGB_MATRIX_STARTUP_SAT 255
    #define RGB_MATRIX_STARTUP_VAL RGB_MATRIX_MAXIMUM_BRIGHTNESS
    #define RGB_MATRIX_STARTUP_SPD 127
    // #define RGB_MATRIX_DISABLE_KEYCODES // 通过键码禁用对 rgb 矩阵的控制（必须使用代码功能来控制该功能）
#endif

// #define LOCKING_SUPPORT_ENABLE // 机械锁定支持。 在键盘映射中使用 KC_LCAP、KC_LNUM 或 KC_LSCR

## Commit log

2022-06-19 add: 添加键盘固件 及固件代码
2022-06-20 上传原理图、PCB 设计
    [BOM_kb_32u4_v1.3.xlsx]
2022-06-21 修改目录
2022-06-21 3528 规格 RGB 文档
2022-06-21 shell v3
    [shell v3.stl]
2022-07-05 电路板 工程文件
2022-07-07 添加机械轴文档
2022-10-24 整合所有键盘设计文件
    [BOM_kb_32u4_v1.3.xlsx, SG84_V1.0_shell_v13_plate.dxf, bottom_plate v2.dxf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]
2022-10-24 参考设计规格书
2022-10-24 凯华轴规格书
2022-10-24 修改定位板
    [sg2-0_61(not_c).dxf]
2022-10-25 更新 sg61 定位板
    [sg2-0_61(not_c).dxf, sg2-0_61.dxf]
2022-10-26 添加 sg_v1 文件
    [BOM_v1.0_v1.0_2022-10-26.xlsx]
2022-10-26 sg61 定位板添加开槽
    [sg2-0_61.dxf]
2022-10-29 添加设计文件
    [BOM_SG-61-USB_SG-61-USB_2022-10-29.xlsx, BOM_SG-61_SG-61_2022-10-29.xlsx, sg2-0_61.dxf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]
2022-10-29 添加 PCB 渲染图
2022-10-30 添加资料
    [SG-61-值锡钢板.dxf, SG-61_USB.step]
2022-11-01 添加 定位板
    [SG-61-定位板.dxf]
2022-11-02 更新 readme
2022-11-02 修改电路板图片
2022-11-06 添加固件代码
2022-11-06 添加通用资料
    [Idapi32.cfg]
2022-11-07 更新固件代码
2022-11-07 修改按键矩阵
2022-11-08 添加固件
2022-11-08 via 配置文件
2022-11-20 调整按键功能
2022-11-20 外壳文件
    [SG-61 v34 底盖.f3z, SG-61 v35 上壳.stl, SG-61 v35 底盖.stl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]
2022-11-20 添加成品图
2022-11-20 调整文件路径
    [BOM_SG-61_SG-61_2022-10-29.xlsx, sg2-0_61.dxf, sg2-0_83.dxf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]
2022-11-20 添加 sg_v2 的 readme
2022-11-22 修改 SG-61 USB 板
2022-12-25 change: 修改 LED封装，使易于安装
2022-12-25 change: 修改 USB 封装，使易于焊接
2022-12-25 change: 更新配列
2022-12-25 change: 更新 PCB 3D 模型
    [3D_SG-61-USB_2022-12-25.step, 3D_SG-61_2022-12-25.step, SG-61_USB.step]
2022-12-25 change: 修改值锡钢网文件
    [DXF_SG-61_2022-12-25_底层锡膏.dxf, SG-61-值锡钢板.dxf]
2022-12-25 change: 删除错误的 PCB 3D 文件
    [3D_SG-61-USB_2022-12-25.step, 3D_SG-61_2022-12-25.step]
2022-12-25 change: 修改 PCB Gerber 文件
2023-02-09 change: 更新 readme，增加 KB84 成品图片，调整资料路径
2023-02-10 change: 增加 成品图片
2023-02-13 add: 增加 指南
2024-04-03 change: 调整指南链接路径
2025-02-28 Update README.md
    添加SG_V2电路板开源地址
